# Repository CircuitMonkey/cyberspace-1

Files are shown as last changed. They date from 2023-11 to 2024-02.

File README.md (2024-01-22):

# cyberspace-1
Card Edge Slot-based 8-bit experimental computer with a Cyberpunk aesthetic.

## Why?
I wanted to make a 8-bit card-edge style computer.  8-bit computers were the first thing I learned to design in school back in the 80's.  Our mid-level education courses involved engineering students wire-wrapping and then programming their own Z80 computer system, with the next semester involving the addition and more programming of peripherals.  So I want to get back to that headspace for a bit.  I see many other hobbyists doing this with Z80, 6502 and even RP2040 chips.  This not sure yet what processor I will choose but it will be something with a good emulator environment on the Mac or Linux.

## About the name...
I want to create a system that has a Cyberpunk aesthetic and in the book Neuromancer, there is a Cyberspace "Deck" called the Cyberspace7 by Ono-Sendai and that implies the existence of Cyberspace 1 through 6.  So for my own amusement I've decided to call this experiment the Cyberspace 1 along with creating logos for Cyberspace product as well as a logo for Ono-Sendai Company.

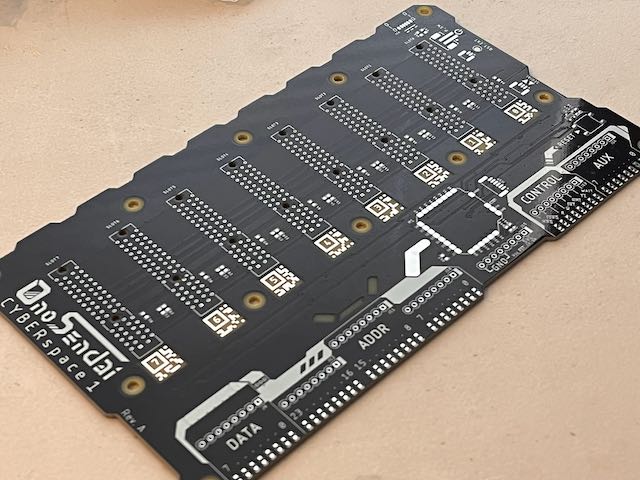
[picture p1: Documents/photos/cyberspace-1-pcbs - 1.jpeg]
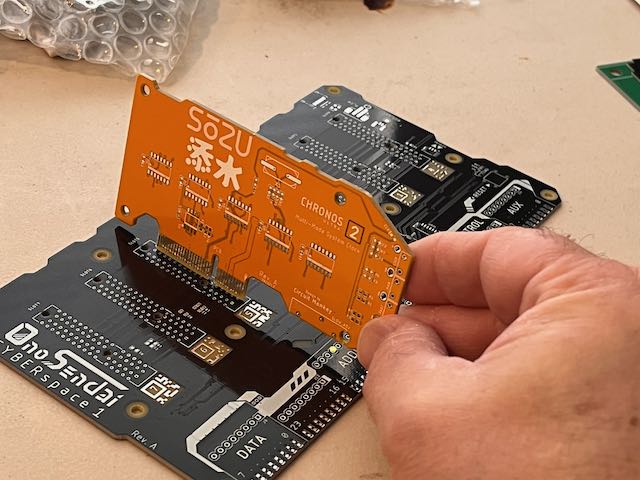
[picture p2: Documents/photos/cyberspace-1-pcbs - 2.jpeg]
&nbsp;&nbsp;&nbsp;&nbsp;

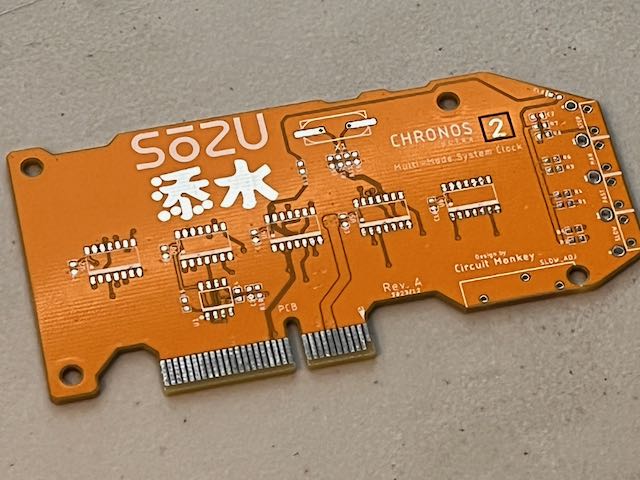
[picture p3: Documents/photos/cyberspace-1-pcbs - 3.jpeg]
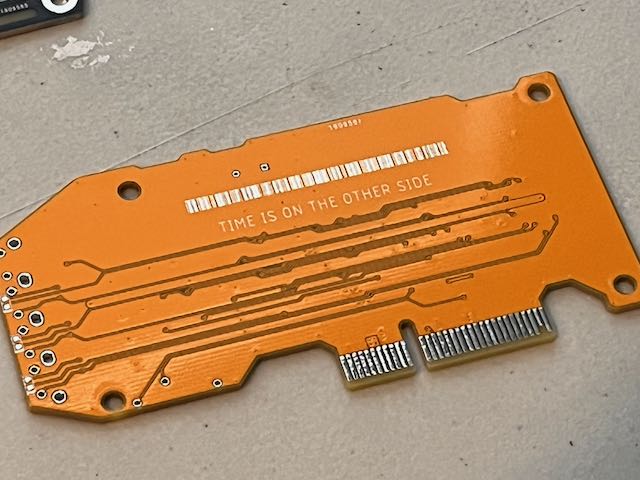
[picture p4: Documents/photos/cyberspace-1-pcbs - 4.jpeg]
&nbsp;&nbsp;&nbsp;&nbsp;

## License
I've decided to make this project with the MIT license.  Do whatever you want with it.

## Release Notes
### 2023 Early November
Created GitHub repository.

### 2023 Mid November
Roughed out basic design for all main boards.  Backplane, 6502, Memory, Clock, Video card.  Placement seems to be satisfactory.

### 2024 January
Bring up of Backplane and Clock board largely succesful!
 * Backplane. No issues found so far.
 * Clock board crystal circuit has error (used Schmidt buffer (HCT14) instead of regular buffer (HCT04). Will fix in later revision.

## To Do
Sound Card, Keyboard and game controller input card.

Each of these peripheral cards are likely to be RP2040 chips masquerading as
custom devices like the Video card will be.  I wish to use USB keyboards and
USB game (perhaps bluetooth?) controllers, so I will look at making a card with multiple USB jacks on it.  The card would handle HID and Storage devices.

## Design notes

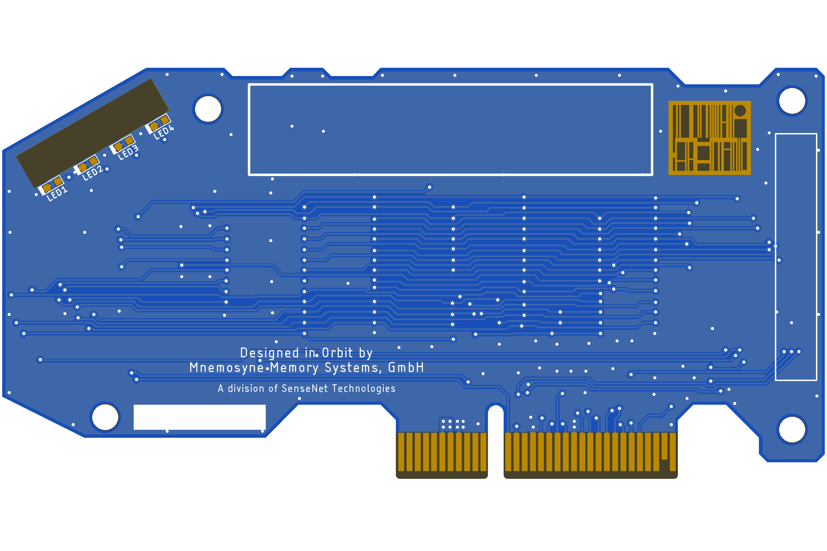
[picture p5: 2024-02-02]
Documents/photos/cyberspace-1-ram-rom-card-preview-back.png

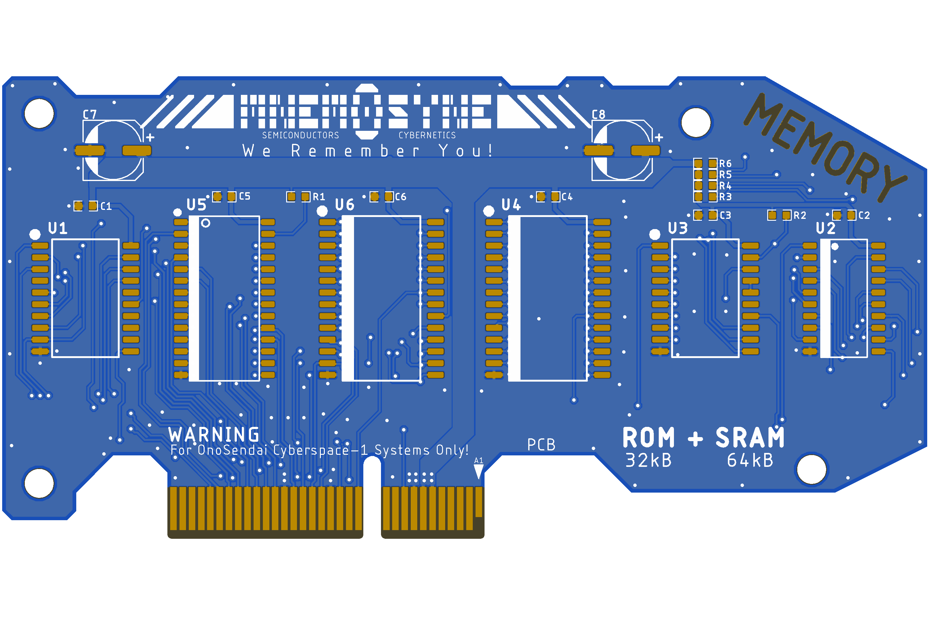
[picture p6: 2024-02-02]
Documents/photos/cyberspace-1-ram-rom-card-preview-front.png

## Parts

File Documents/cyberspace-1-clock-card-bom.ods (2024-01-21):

Cyberspace-1 Clock PCB |  |  |  |  | Rev. A |  | (2023-12)
Part | Value | Device | Package | Description | COST01 | COST10 | COST100 | MFR | MPN | LINK
PCB | PCB Fab | CYBERSPACE-1-CARD-1A | CYBERSPACE-CARD-TYPE-1A | Card for the CyberSpace 1 System | $5.00 | $2.00 | $0.70 | Circuit Monkey
R1 | 4.7K | RESISTOR0603 | 0603-RES | Resistor | $0.10 | $0.05 | $0.02
R2 | 4.7K | RESISTOR0603 | 0603-RES | Resistor | $0.10 | $0.05 | $0.02
R3 | 4.7K | RESISTOR0603 | 0603-RES | Resistor | $0.10 | $0.05 | $0.02
R4 | 1K | RESISTOR0603 | 0603-RES | Resistor | $0.10 | $0.05 | $0.02
R5 | 1K | RESISTOR0603 | 0603-RES | Resistor | $0.10 | $0.05 | $0.02
R6 | 1K | RESISTOR0603 | 0603-RES | Resistor | $0.10 | $0.05 | $0.02
R7 | 1K | RESISTOR0603 | 0603-RES | Resistor | $0.10 | $0.05 | $0.02
R8 | 1K | RESISTOR0603 | 0603-RES | Resistor | $0.10 | $0.05 | $0.02
R9 | 1K | RESISTOR0603 | 0603-RES | Resistor | $0.10 | $0.05 | $0.02
R10 | 1K | RESISTOR0603 | 0603-RES | Resistor | $0.10 | $0.05 | $0.02
R11 | 1K | RESISTOR0603 | 0603-RES | Resistor | $0.10 | $0.05 | $0.02
R12 | 1M | RESISTOR0603 | 0603-RES | Resistor | $0.10 | $0.05 | $0.02
R13 | 2K | RESISTOR0603 | 0603-RES | Resistor | $0.10 | $0.05 | $0.02
C1 | 0.1uF | CAPACITOR0603 | 0603-CAP | Capacitor | $0.12 | $0.09 | $0.05
C2 | 1uF | CAPACITOR0603 | 0603-CAP | Capacitor | $0.12 | $0.09 | $0.05
C3 | 0.1uF | CAPACITOR0603 | 0603-CAP | Capacitor | $0.12 | $0.09 | $0.05
C4 | 0.1uF | CAPACITOR0603 | 0603-CAP | Capacitor | $0.12 | $0.09 | $0.05
C5 | 22pF | CAPACITOR0603 | 0603-CAP | Capacitor | $0.12 | $0.09 | $0.05
C6 | 22pF | CAPACITOR0603 | 0603-CAP | Capacitor | $0.12 | $0.09 | $0.05
C7 | 0.1uF | CAPACITOR0603 | 0603-CAP | Capacitor | $0.12 | $0.09 | $0.05
C8 | 0.1uF | CAPACITOR0603 | 0603-CAP | Capacitor | $0.12 | $0.09 | $0.05
C9 | 0.1uF | CAPACITOR0603 | 0603-CAP | Capacitor | $0.12 | $0.09 | $0.05
C10 | 0.1uF | CAPACITOR0603 | 0603-CAP | Capacitor | $0.12 | $0.09 | $0.05
U1 | 555 | 555SOIC | SOP08 | Timer Chip | $0.70 | $0.66 | $0.40 | TI | NE555PSR
U2 | HCT08 | 74HCT08D | SOP14 | Quad AND Gate | $0.50 | $0.35 | $0.20 |  | 74HCT08D
U3 | HCT08 | 74HCT08D | SOP14 | Quad AND Gate | $0.50 | $0.35 | $0.20 |  | 74HCT08D
U4 | HCT00 | 74AHCT00D | SOP14 | Quad NAND Gate |  |  |  |  | 74HCT00D
U5 | HCT14 | 74HCT14D | SOP14 | Hex Schmidt Inverter | $0.45 | $0.35 | $0.20 |  | 74HCT14D
U6 | HCT32 | 74HCT32D | SOP14 | Quad OR | $0.45 | $0.35 | $0.20 |  | 74HCT32D
SLOW_ADJ |  | CERMET_MULTI_TURN-3006P | CERMET_MULTI_3006P_THD | Cermet Style, Multi-turn Potentiometer | $2.00 | $1.70 | $1.40 | BOURNES | 3006P | https://www.taydaelectronics.com/potentiometer-variable-resistors/cermet-potentiometers.html
CLK | RED | SMT0603 | SMD_0603 | LED SMT | $0.20 | $0.17 | $0.14
L_FAST | BLU | SMT0603 | SMD_0603 | LED SMT | $0.20 | $0.17 | $0.14
L_MAN | BLU | SMT0603 | SMD_0603 | LED SMT | $0.20 | $0.17 | $0.14
L_SLOW | BLU | SMT0603 | SMD_0603 | LED SMT | $0.20 | $0.17 | $0.14
MAN |  | TACTILESPST-RA-6X6 | TC-0202 | Push Sw. | $0.20 | $0.15 | $0.13 | CUI | TS11-674-65-*
FAST |  | TACTILESPST-RA-6X6 | TC-0202 | Push Sw. | $0.20 | $0.15 | $0.13 | CUI | TS11-674-55-*
SLOW |  | TACTILESPST-RA-6X6 | TC-0202 | Push Sw. | $0.20 | $0.15 | $0.13 | CUI | TS11-674-55-*
STEP |  | TACTILESPST-RA-6X6 | TC-0202 | Push Sw. | $0.20 | $0.15 | $0.13 | CUI | TS11-674-55-*
X1 | 1-14MHz | 2PATS_DUAL_SMD_THD | ATSXXXX | Crystal

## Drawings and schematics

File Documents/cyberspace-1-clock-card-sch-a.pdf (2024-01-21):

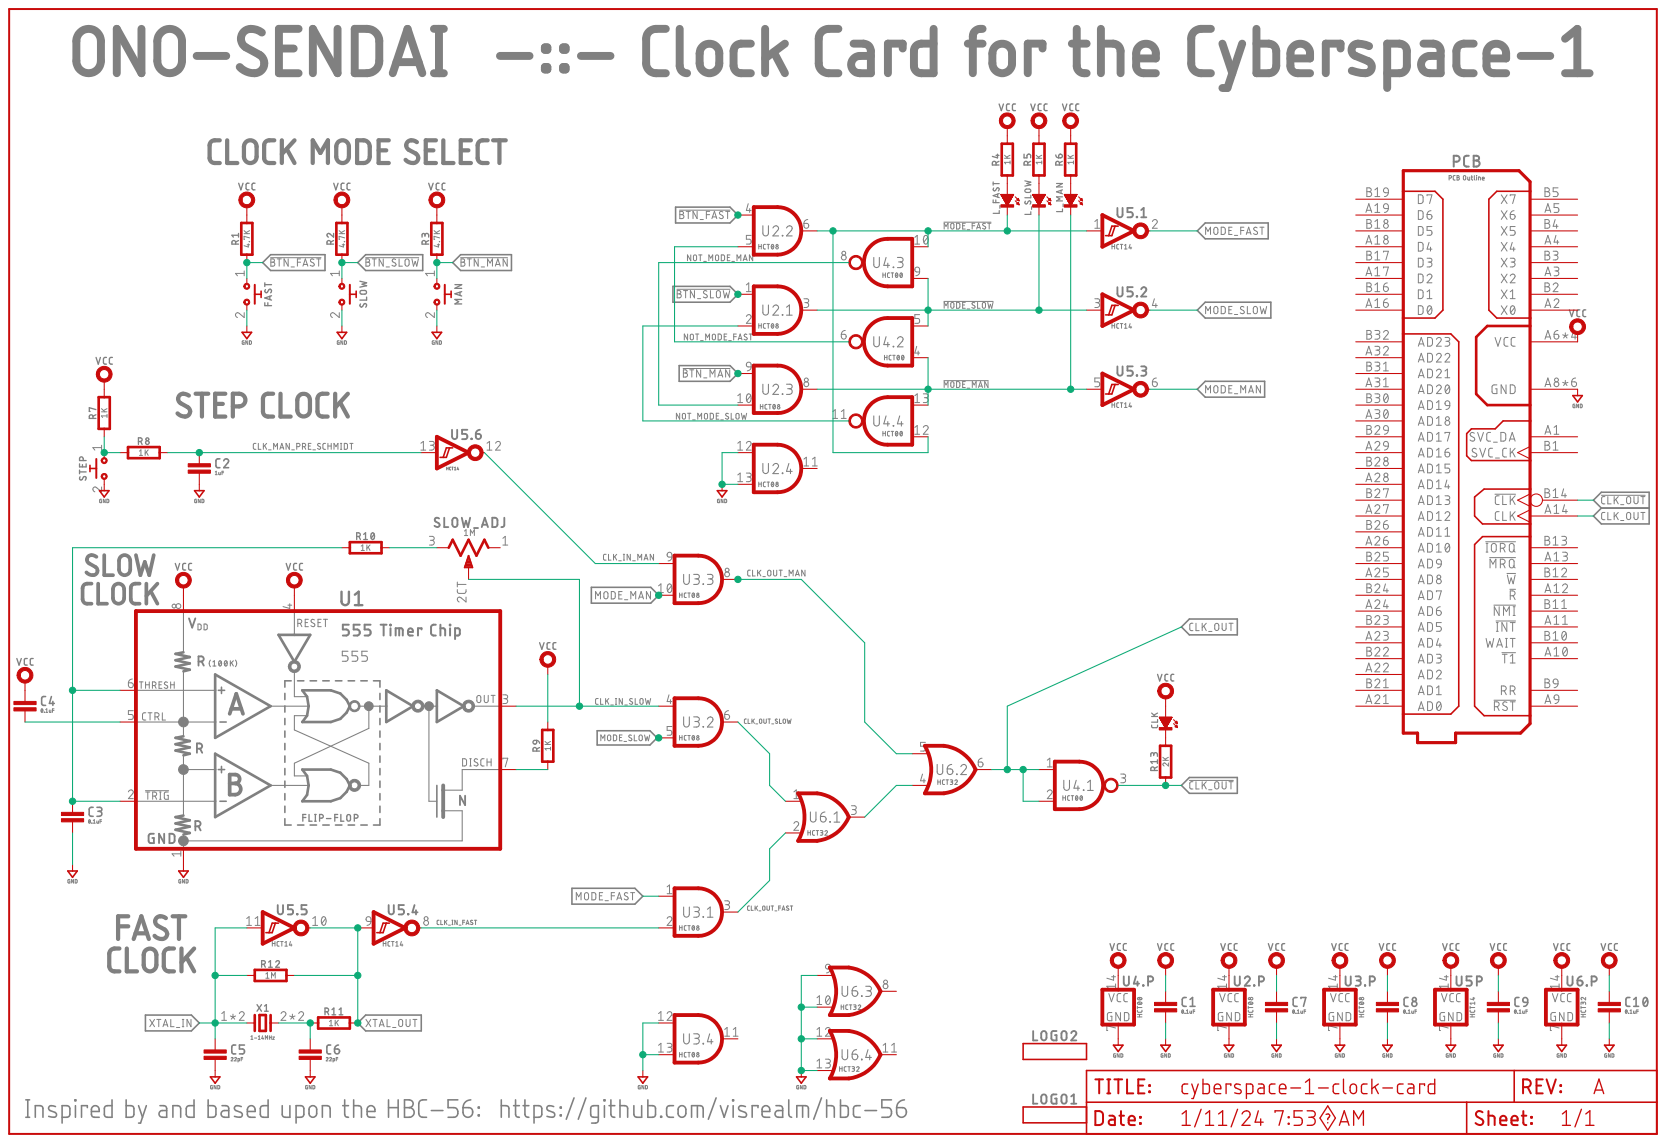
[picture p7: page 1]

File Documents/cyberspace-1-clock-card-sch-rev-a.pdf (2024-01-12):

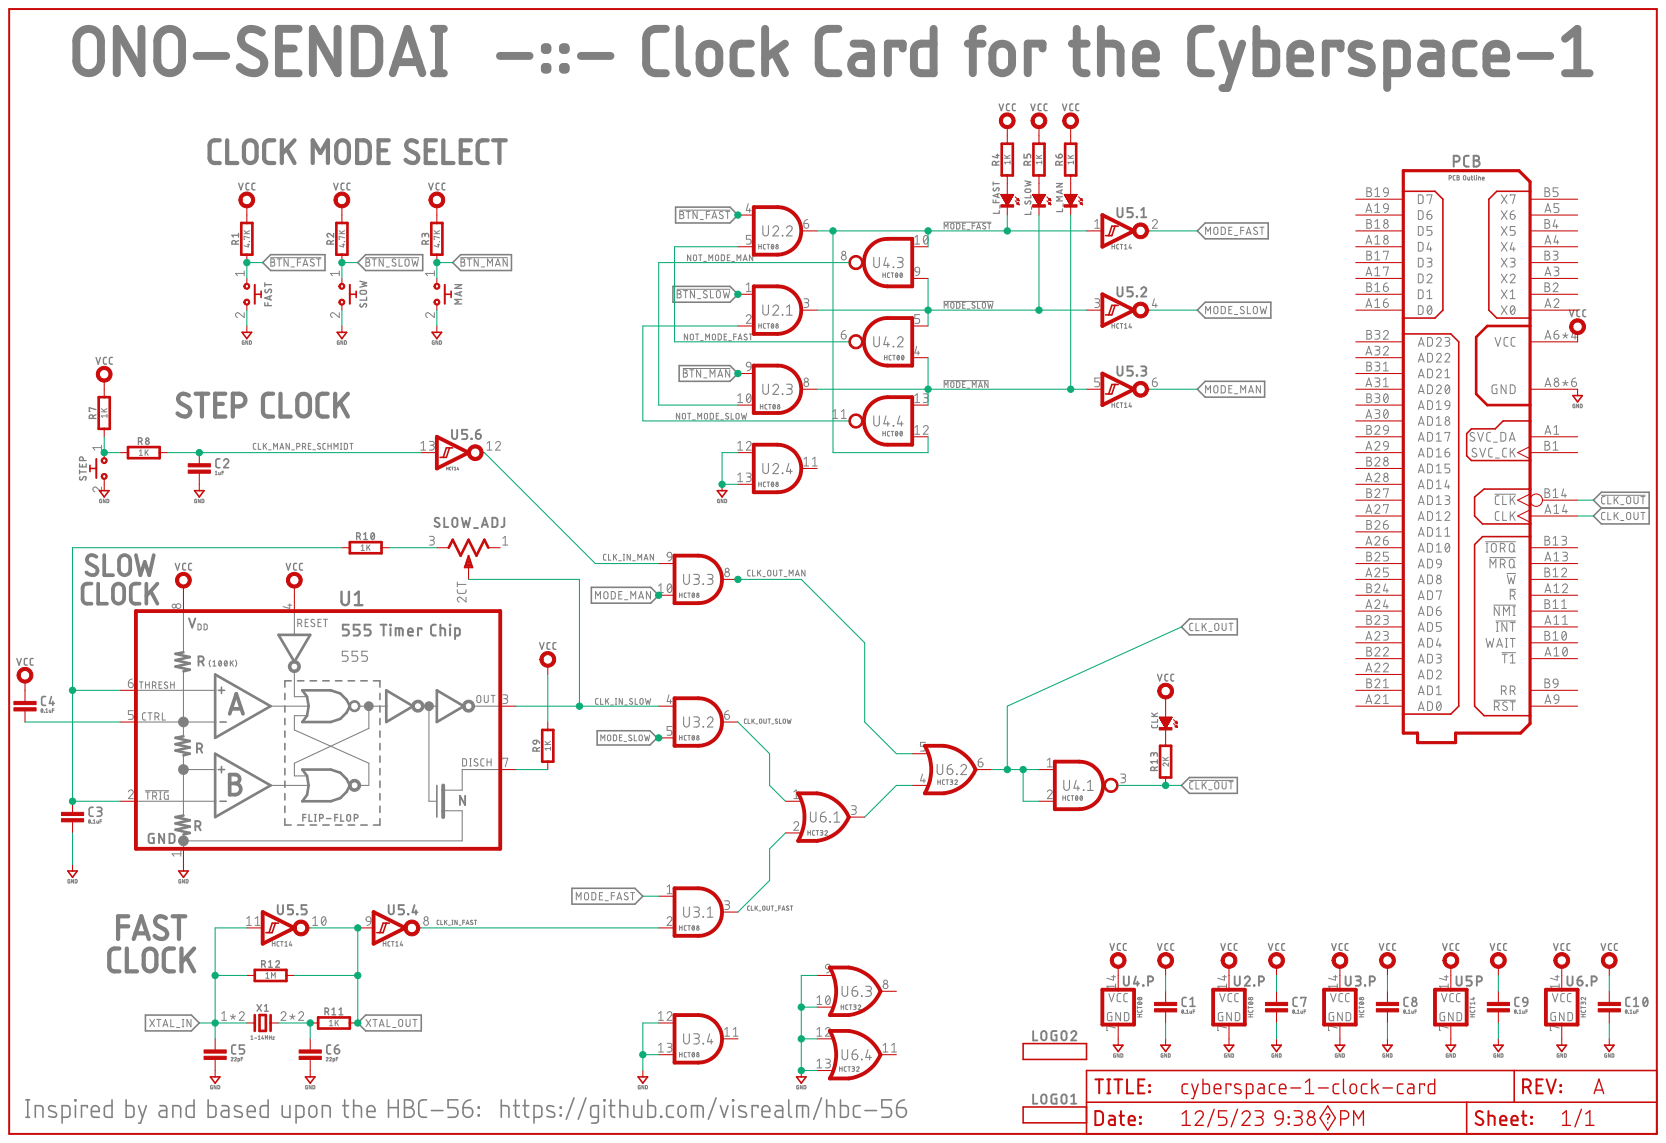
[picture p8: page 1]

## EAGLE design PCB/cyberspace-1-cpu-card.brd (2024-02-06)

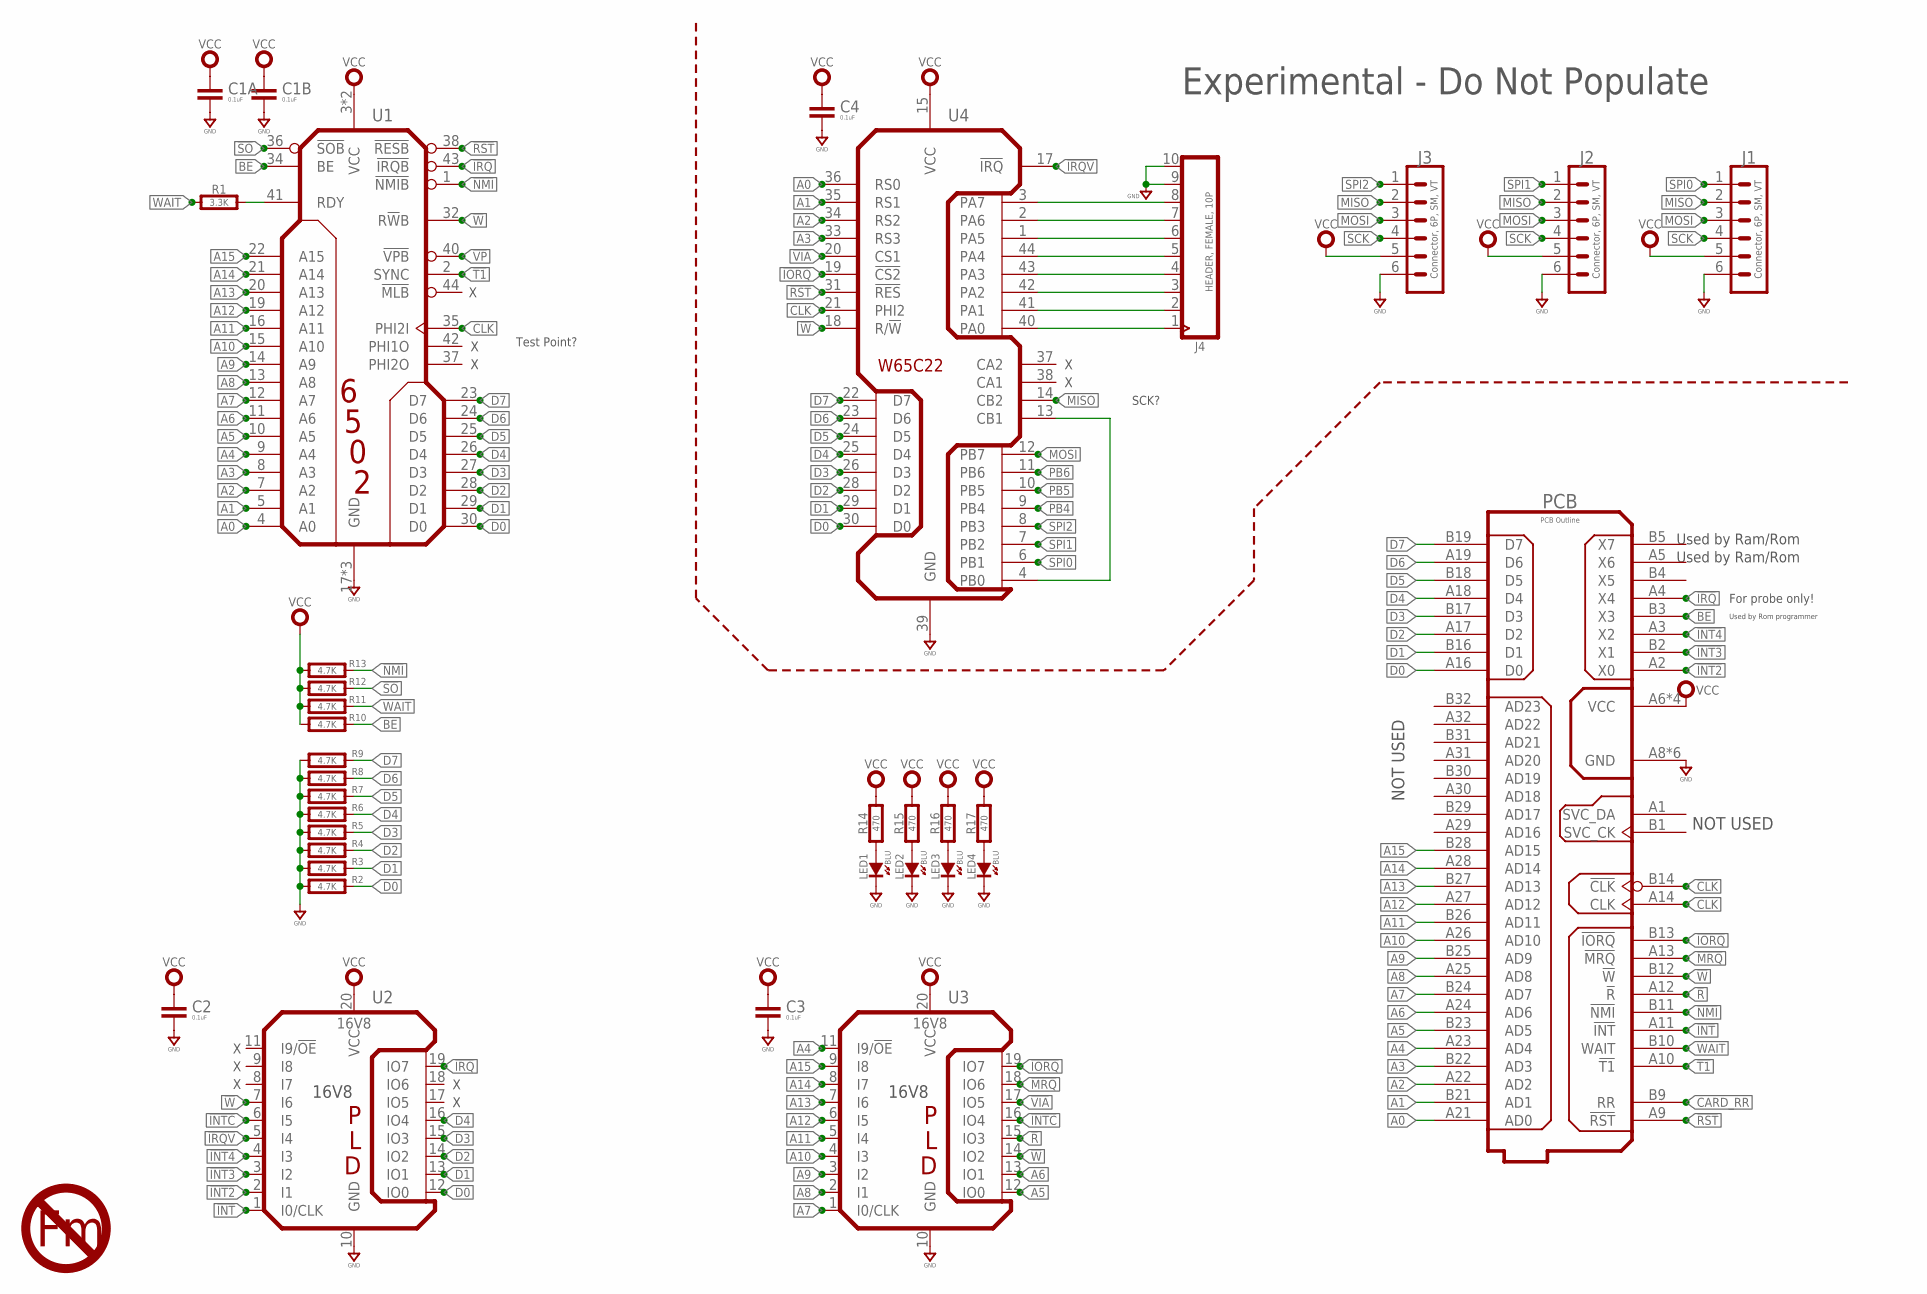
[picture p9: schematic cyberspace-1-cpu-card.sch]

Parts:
C1A, C1B, C2, C3, C4: 0.1uF; 0603-CAP
J1, J2, J3: Connector, 6P, SM, VT; BM06B-SRSS-TB
J4: HEADER, FEMALE, 10P; H10-2.54
LED1, LED2, LED3, LED4: BLU; SMD_0603
PCB: PCB Outline; CYBERSPACE-CARD-TYPE-1A
R1: 3.3K; 0603-RES
R2, R3, R4, R5, R6, R7, R8, R9, R10, R11, R12, R13: 4.7K; 0603-RES
R14, R15, R16, R17: 470; 0603-RES
U1: 6502 Processor; TQFP-44-10
U2, U3: 16V8; SOP20
U4: W65C22; TQFP-44-10
U$2: NO-FERMIUM-5MM

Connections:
!CLK: PCB.B14 (!CLK)
!INT: PCB.A11 (!INT), U2.1 (I0/CLK)
!INT2: PCB.A2 (X0), U2.2 (I1)
!INT3: PCB.B2 (X1), U2.3 (I2)
!INT4: PCB.A3 (X2), U2.4 (I3)
!INTC: U2.6 (I5), U3.16 (IO4)
!IORQ: PCB.B13 (!IORQ), U3.19 (IO7), U4.19 (!CS2)
!IRQ: PCB.A4 (X4), U1.43 (!IRQB), U2.19 (IO7)
!IRQV: U2.5 (I4), U4.17 (!IRQ)
!MRQ: PCB.A13 (!MRQ), U3.18 (IO6)
!NMI: PCB.B11 (!NMI), R13.2, U1.1 (!NMIB)
!R: PCB.A12 (!R), U3.15 (IO3)
!RST: PCB.A9 (!RST), U1.38 (!RESB), U4.31 (!RES)
!SO: R12.2, U1.36 (!SOB)
!T1: PCB.A10 (!T1), U1.2 (SYNC)
!VIA: U3.17 (IO5), U4.20 (CS1)
!VP: U1.40 (!VPB)
!W: PCB.B12 (!W), U1.32 (R!W!B), U2.7 (I6), U3.14 (IO2), U4.18 (R/!W)
A0: PCB.A21 (AD0), U1.4 (A0), U4.36 (RS0)
A1: PCB.B21 (AD1), U1.5 (A1), U4.35 (RS1)
A2: PCB.A22 (AD2), U1.7 (A2), U4.34 (RS2)
A3: PCB.B22 (AD3), U1.8 (A3), U4.33 (RS3)
A4: PCB.A23 (AD4), U1.9 (A4), U3.11 (I9/!OE)
A5: PCB.B23 (AD5), U1.10 (A5), U3.12 (IO0)
A6: PCB.A24 (AD6), U1.11 (A6), U3.13 (IO1)
A7: PCB.B24 (AD7), U1.12 (A7), U3.1 (I0/CLK)
A8: PCB.A25 (AD8), U1.13 (A8), U3.2 (I1)
A9: PCB.B25 (AD9), U1.14 (A9), U3.3 (I2)
A10: PCB.A26 (AD10), U1.15 (A10), U3.4 (I3)
A11: PCB.B26 (AD11), U1.16 (A11), U3.5 (I4)
A12: PCB.A27 (AD12), U1.19 (A12), U3.6 (I5)
A13: PCB.B27 (AD13), U1.20 (A13), U3.7 (I6)
A14: PCB.A28 (AD14), U1.21 (A14), U3.8 (I7)
A15: PCB.B28 (AD15), U1.22 (A15), U3.9 (I8)
BE: PCB.B3 (X3), R10.2, U1.34 (BE)
CARD_RR: PCB.B9 (RR)
CLK: PCB.A14 (CLK), U1.35 (PHI2I), U4.21 (PHI2)
D0: PCB.A16 (D0), R2.2, U1.30 (D0), U2.12 (IO0), U4.30 (D0)
D1: PCB.B16 (D1), R3.2, U1.29 (D1), U2.13 (IO1), U4.29 (D1)
D2: PCB.A17 (D2), R4.2, U1.28 (D2), U2.14 (IO2), U4.28 (D2)
D3: PCB.B17 (D3), R5.2, U1.27 (D3), U2.15 (IO3), U4.26 (D3)
D4: PCB.A18 (D4), R6.2, U1.26 (D4), U2.16 (IO4), U4.25 (D4)
D5: PCB.B18 (D5), R7.2, U1.25 (D5), U4.24 (D5)
D6: PCB.A19 (D6), R8.2, U1.24 (D6), U4.23 (D6)
D7: PCB.B19 (D7), R9.2, U1.23 (D7), U4.22 (D7)
GND: C1A.2, C1B.2, C2.2, C3.2, C4.2, J1.6, J2.6, J3.6, J4.9, J4.10, LED1.K (C), LED2.K (C), LED3.K (C), LED4.K (C), PCB.A8 (GND), PCB.A15 (GND), PCB.A20 (GND), PCB.B8 (GND), PCB.B15 (GND), PCB.B20 (GND), R2.1, R3.1, R4.1, R5.1, R6.1, R7.1, R8.1, R9.1, U1.17 (GND), U1.18 (GND), U1.39 (GND), U2.10 (GND), U3.10 (GND), U4.39 (GND)
MISO: J1.2, J2.2, J3.2, U4.14 (CB2)
MOSI: J1.3, J2.3, J3.3, U4.12 (PB7)
unnamed: J4.1, U4.40 (PA0)
unnamed: J4.2, U4.41 (PA1)
unnamed: J4.3, U4.42 (PA2)
unnamed: J4.4, U4.43 (PA3)
unnamed: J4.5, U4.44 (PA4)
unnamed: J4.6, U4.1 (PA5)
unnamed: J4.7, U4.2 (PA6)
unnamed: J4.8, U4.3 (PA7)
unnamed: U4.4 (PB0), U4.13 (CB1)
unnamed: R1.2, U1.41 (RDY)
unnamed: LED1.A, R14.1
unnamed: LED2.A, R15.1
unnamed: LED3.A, R16.1
unnamed: LED4.A, R17.1
PB4: U4.9 (PB4)
PB5: U4.10 (PB5)
PB6: U4.11 (PB6)
SCK: J1.4, J2.4, J3.4
SPI0: J1.1, U4.6 (PB1)
SPI1: J2.1, U4.7 (PB2)
SPI2: J3.1, U4.8 (PB3)
VCC: C1A.1, C1B.1, C2.1, C3.1, C4.1, J1.5, J2.5, J3.5, PCB.A6 (VCC), PCB.A7 (VCC), PCB.B6 (VCC), PCB.B7 (VCC), R10.1, R11.1, R12.1, R13.1, R14.2, R15.2, R16.2, R17.2, U1.3 (VCC), U1.31 (VCC), U2.20 (VCC), U3.20 (VCC), U4.15 (VCC)
WAIT: PCB.B10 (WAIT), R1.1, R11.2

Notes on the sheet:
Experimental - Do Not Populate
NOT USED
Used by Ram/Rom
X X X
X X
SCK?
Test Point?
For probe only!
Used by Rom programmer

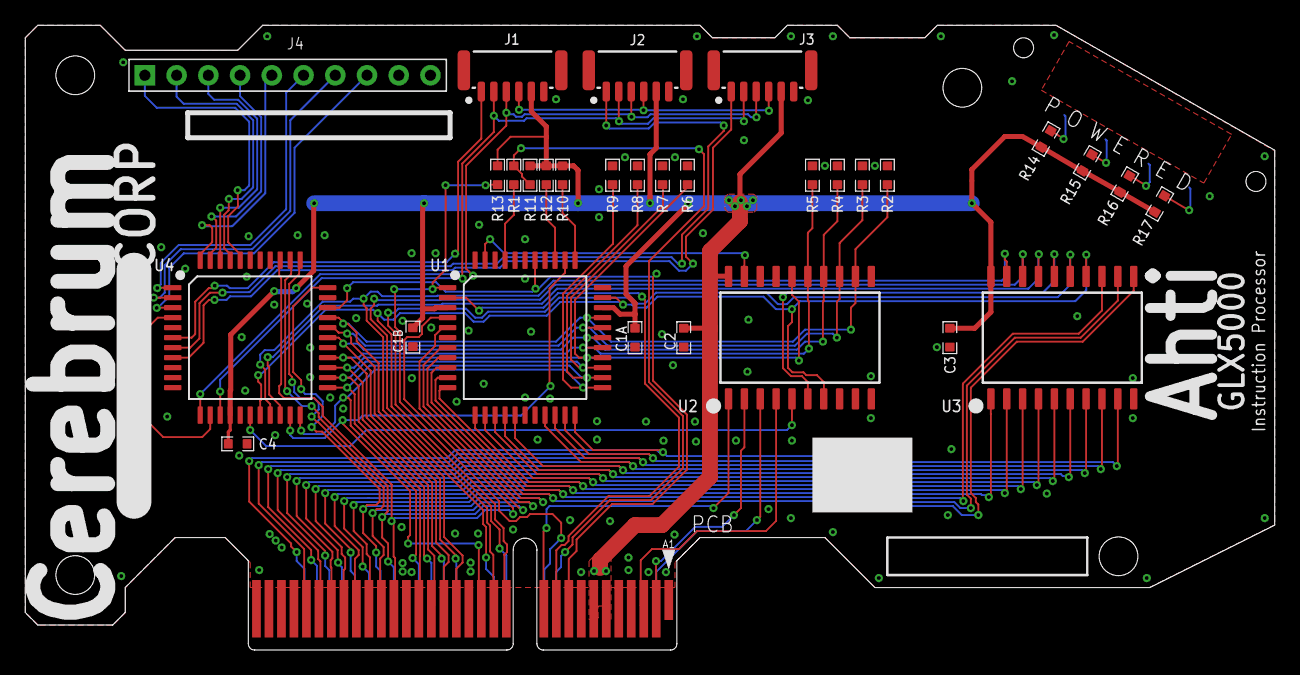
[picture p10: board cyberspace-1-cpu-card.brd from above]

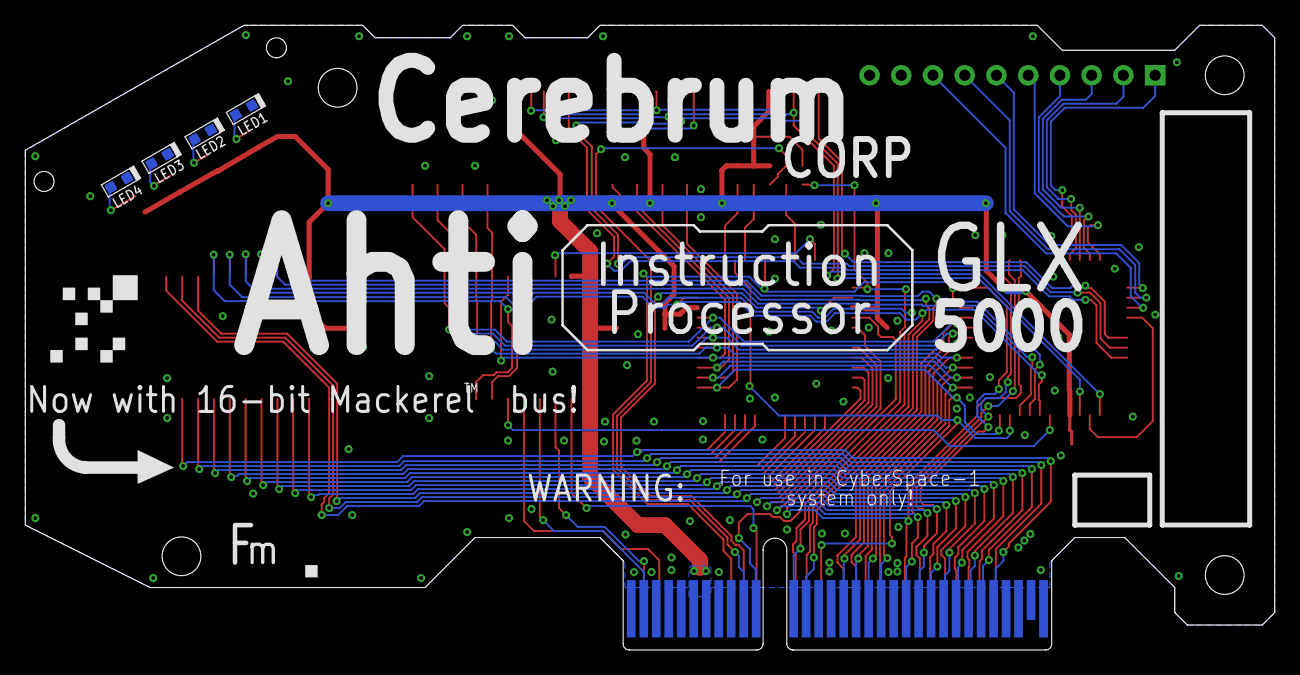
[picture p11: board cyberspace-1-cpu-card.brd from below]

Board: 2 copper layers, 100.0 x 50.0 mm, 36 parts (5 on the bottom side), 65 nets.

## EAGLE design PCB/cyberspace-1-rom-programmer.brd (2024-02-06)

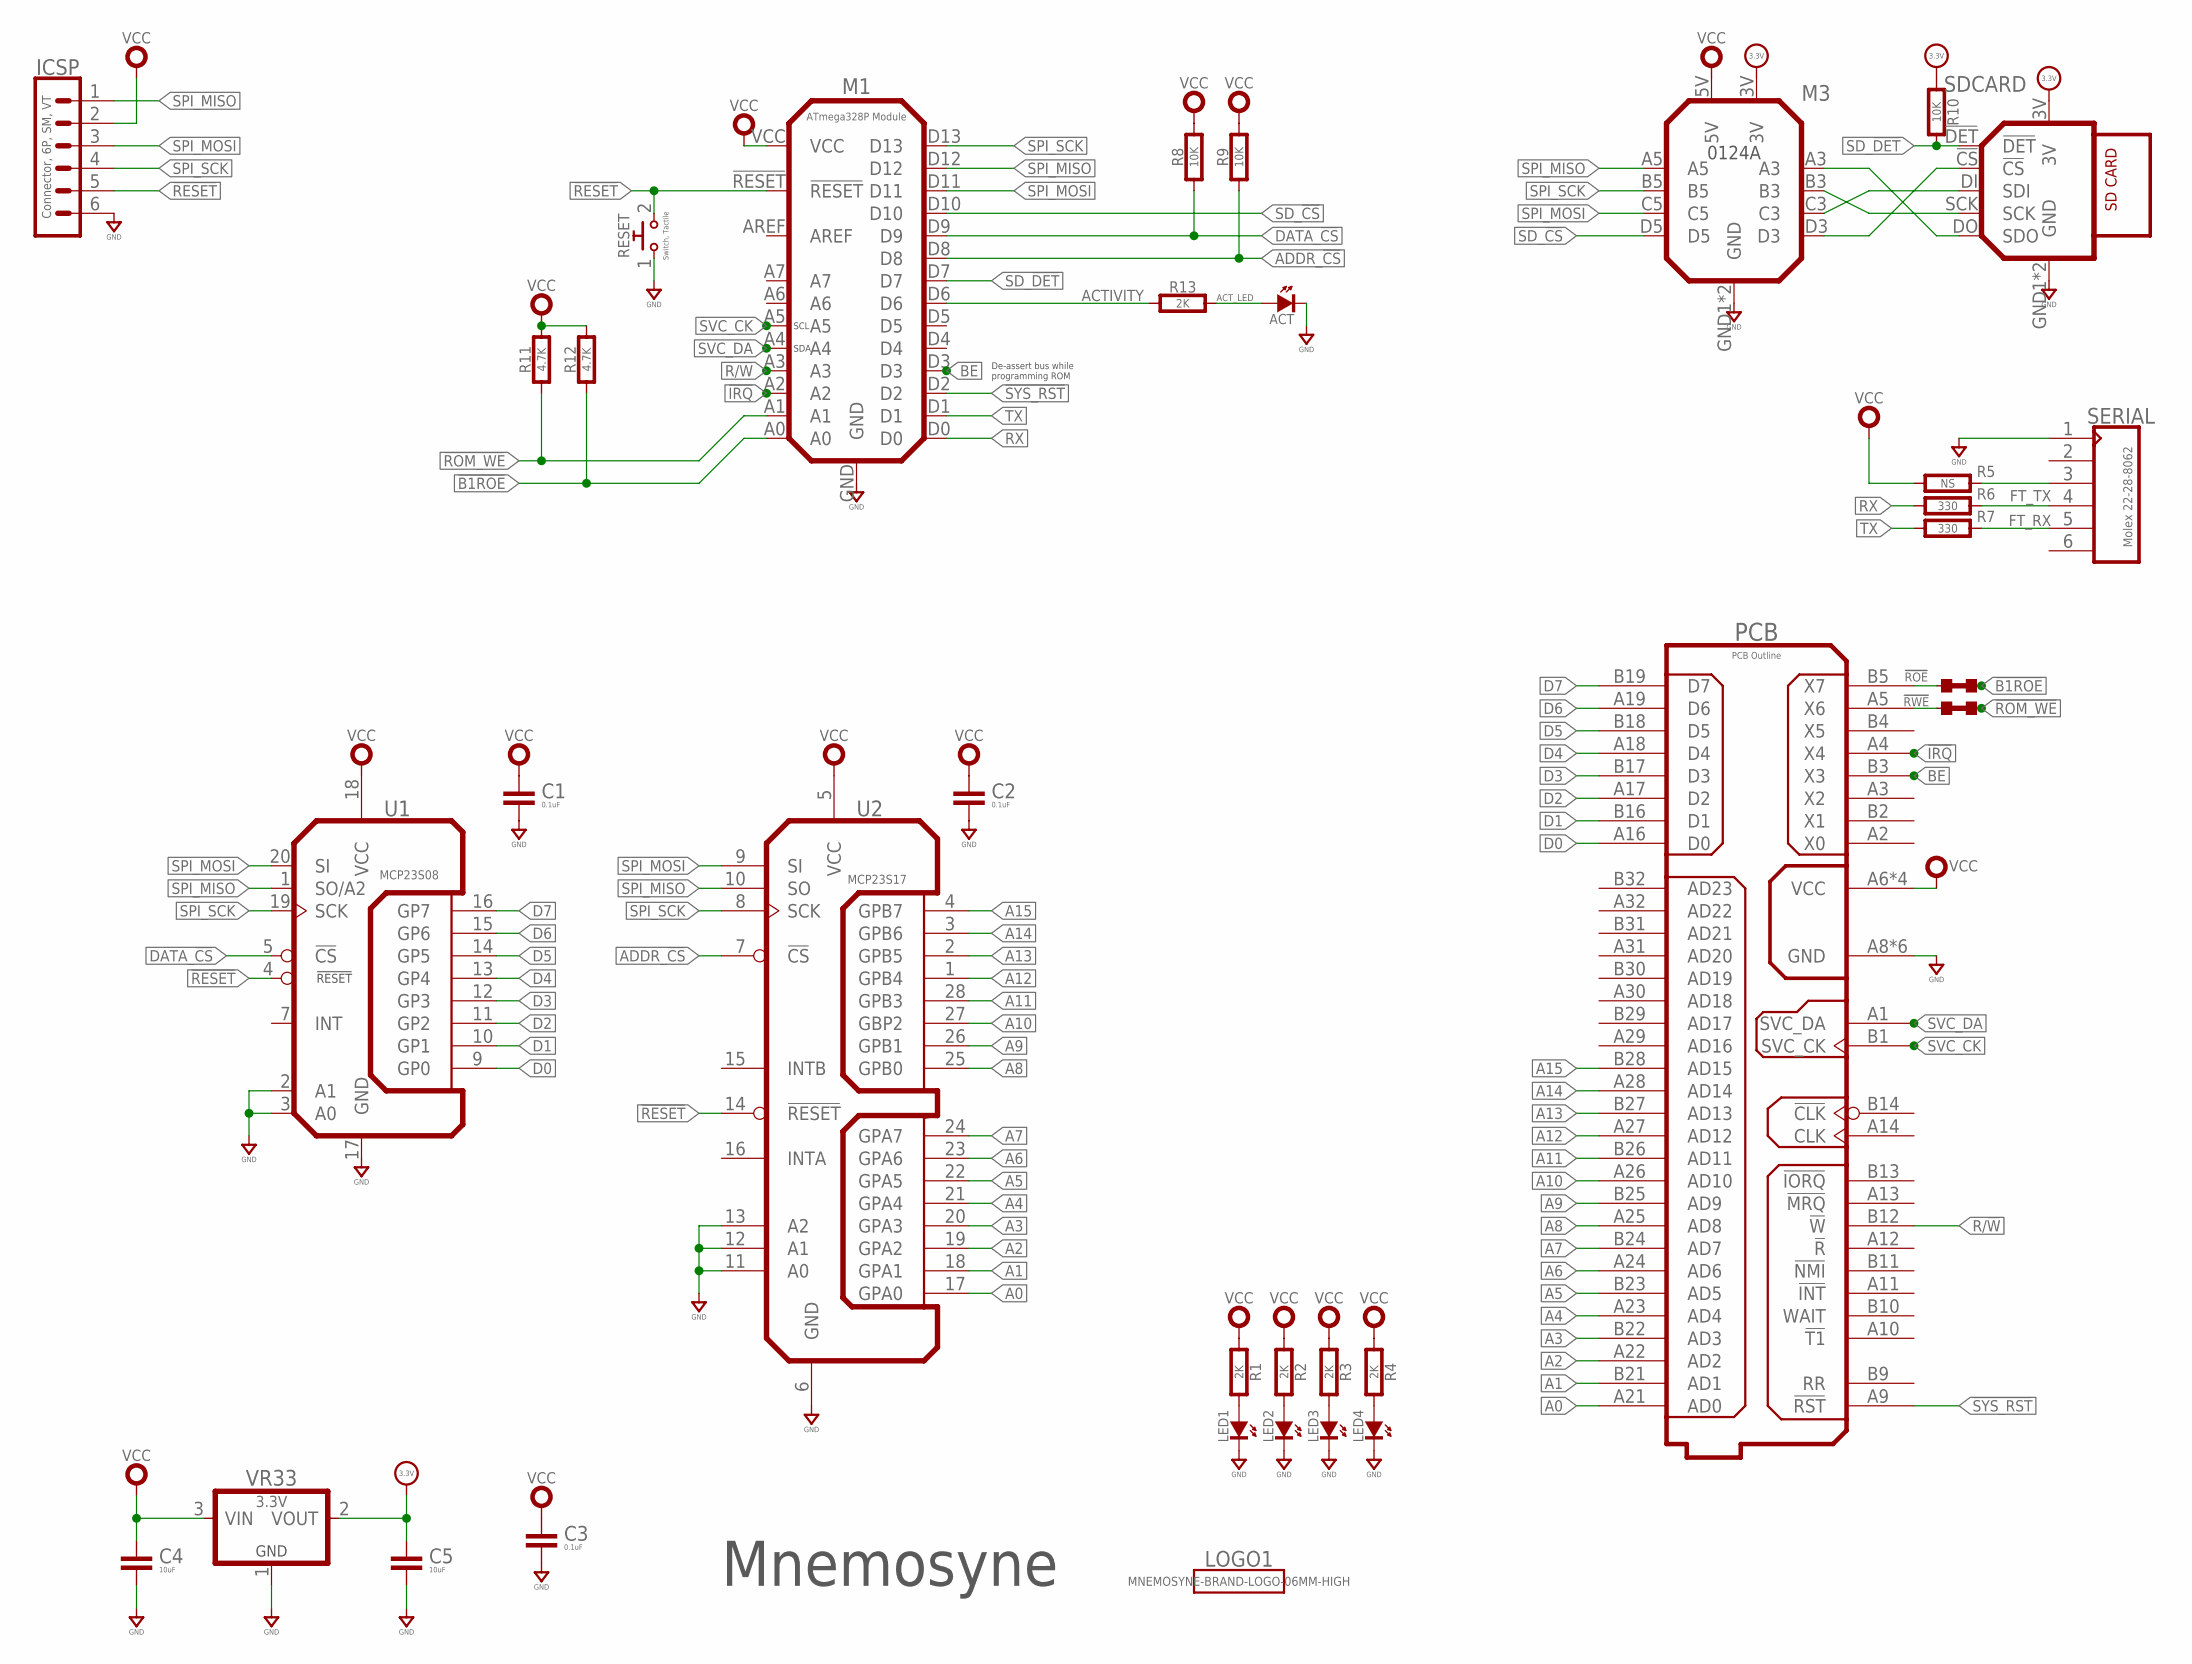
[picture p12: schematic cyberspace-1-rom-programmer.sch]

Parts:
!ROE: NP; 0603-SHORT
!RWE: NP; 0603-SHORT
ACT: SMT0603; SMD_0603
C1, C2, C3: 0.1uF; 0603-CAP
C4, C5: 10uF; 0603-CAP
ICSP: Connector, 6P, SM, VT; BM06B-SRSS-TB
LED1, LED2, LED3, LED4: SMT0603; SMD_0603
LOGO1: MNEMOSYNE-BRAND-LOGO-06MM-HIGH; MNEMOSYNE-06MM
M1: ATmega328P Module; 0119A
M3: 0124A
PCB: PCB Outline; CYBERSPACE-CARD-TYPE-1A
R1, R2, R3, R4, R13: 2K; 0603-RES
R5: NS; 0603-RES
R6, R7: 330; 0603-RES
R8, R9, R10: 10K; 0603-RES
R11, R12: 4.7K; 0603-RES
RESET: Switch, Tactile; TC-0202
SDCARD: 0127REV-A; 0127A
SERIAL: Molex 22-28-8062; MA06X1-RA-THD
U1: MCP23S08; QFN-20
U2: MCP23S17; QFN-28-6X6
VR33: 3.3V; SOT-23

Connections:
!B1ROE: !ROE.4 (2), M1.A0, R12.1
!IRQ: M1.A2, PCB.A4 (X4)
!RESET: ICSP.5, M1.!RESET, RESET.2, U1.4 (!RESET), U2.14 (!RESET)
!ROM_WE: !RWE.4 (2), M1.A1, R11.1
!SYS_RST: M1.D2, PCB.A9 (!RST)
+3.3V: C5.1, M3.3V, R10.2, SDCARD.3V, VR33.2 (VOUT)
A0: PCB.A21 (AD0), U2.17 (GPA0)
A1: PCB.B21 (AD1), U2.18 (GPA1)
A2: PCB.A22 (AD2), U2.19 (GPA2)
A3: PCB.B22 (AD3), U2.20 (GPA3)
A4: PCB.A23 (AD4), U2.21 (GPA4)
A5: PCB.B23 (AD5), U2.22 (GPA5)
A6: PCB.A24 (AD6), U2.23 (GPA6)
A7: PCB.B24 (AD7), U2.24 (GPA7)
A8: PCB.A25 (AD8), U2.25 (GPB0)
A9: PCB.B25 (AD9), U2.26 (GPB1)
A10: PCB.A26 (AD10), U2.27 (GBP2)
A11: PCB.B26 (AD11), U2.28 (GPB3)
A12: PCB.A27 (AD12), U2.1 (GPB4)
A13: PCB.B27 (AD13), U2.2 (GPB5)
A14: PCB.A28 (AD14), U2.3 (GPB6)
A15: PCB.B28 (AD15), U2.4 (GPB7)
ACTIVITY: M1.D6, R13.1
ACT_LED: ACT.A, R13.2
ADDR_!CS: M1.D8, R9.1, U2.7 (!CS)
BE: M1.D3, PCB.B3 (X3)
D0: PCB.A16 (D0), U1.9 (GP0)
D1: PCB.B16 (D1), U1.10 (GP1)
D2: PCB.A17 (D2), U1.11 (GP2)
D3: PCB.B17 (D3), U1.12 (GP3)
D4: PCB.A18 (D4), U1.13 (GP4)
D5: PCB.B18 (D5), U1.14 (GP5)
D6: PCB.A19 (D6), U1.15 (GP6)
D7: PCB.B19 (D7), U1.16 (GP7)
DATA_!CS: M1.D9, R8.1, U1.5 (!CS)
FT_RX: R7.1, SERIAL.5
FT_TX: R6.1, SERIAL.4
GND: ACT.K (C), C1.2, C2.2, C3.2, C4.2, C5.2, ICSP.6, LED1.K (C), LED2.K (C), LED3.K (C), LED4.K (C), M1.GND, M3.GND1 (GND), M3.GND2 (GND), PCB.A8 (GND), PCB.A15 (GND), PCB.A20 (GND), PCB.B8 (GND), PCB.B15 (GND), PCB.B20 (GND), RESET.1, SDCARD.GND1 (GND), SDCARD.GND2 (GND), SERIAL.1, U1.2 (A1), U1.3 (A0), U1.17 (GND), U2.6 (GND), U2.11 (A0), U2.12 (A1), U2.13 (A2), VR33.1 (GND)
unnamed: M3.A3, SDCARD.DO (SDO)
unnamed: M3.B3, SDCARD.SCK
unnamed: M3.C3, SDCARD.DI (SDI)
unnamed: R5.1, SERIAL.3
unnamed: M3.D3, SDCARD.!CS
unnamed: LED1.A, R1.2
unnamed: LED2.A, R2.2
unnamed: LED3.A, R3.2
unnamed: !ROE.3 (1), PCB.B5 (X7)
unnamed: !RWE.3 (1), PCB.A5 (X6)
unnamed: LED4.A, R4.2
R/!W: M1.A3, PCB.B12 (!W)
RX: M1.D0, R6.2
SD_!CS: M1.D10, M3.D5
SD_!DET: M1.D7, R10.1, SDCARD.!DET
SPI_MISO: ICSP.1, M1.D12, M3.A5, U1.1 (SO/A2), U2.10 (SO)
SPI_MOSI: ICSP.3, M1.D11, M3.C5, U1.20 (SI), U2.9 (SI)
SPI_SCK: ICSP.4, M1.D13, M3.B5, U1.19 (SCK), U2.8 (SCK)
SVC_CK: M1.A5, PCB.B1 (SVC_CK)
SVC_DA: M1.A4, PCB.A1 (SVC_DA)
TX: M1.D1, R7.2
VCC: C1.1, C2.1, C3.1, C4.1, ICSP.2, M1.VCC, M3.5V, PCB.A6 (VCC), PCB.A7 (VCC), PCB.B6 (VCC), PCB.B7 (VCC), R1.1, R2.1, R3.1, R4.1, R5.2, R8.2, R9.2, R11.2, R12.2, U1.18 (VCC), U2.5 (VCC), VR33.3 (VIN)

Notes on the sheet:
SDA
SCL
Mnemosyne
De-assert bus while programming ROM

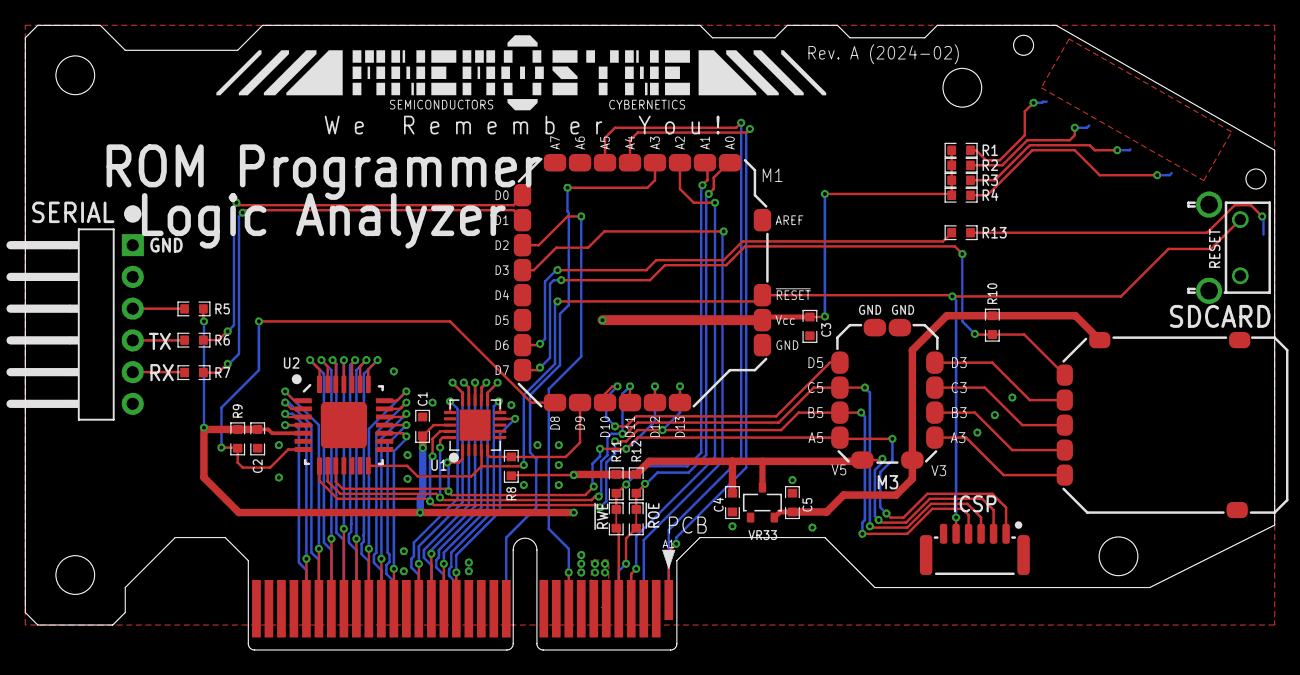
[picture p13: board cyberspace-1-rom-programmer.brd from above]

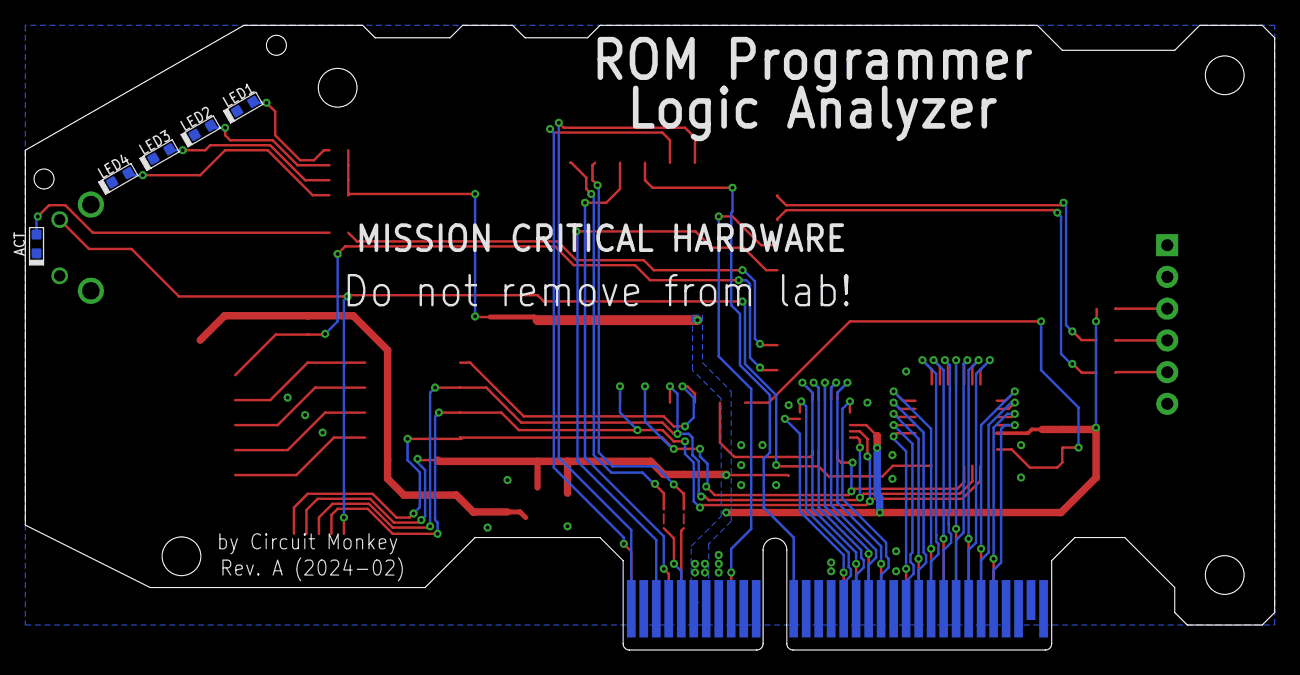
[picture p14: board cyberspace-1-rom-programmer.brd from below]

Board: 2 copper layers, 100.0 x 50.0 mm, 36 parts (5 on the bottom side), 60 nets.

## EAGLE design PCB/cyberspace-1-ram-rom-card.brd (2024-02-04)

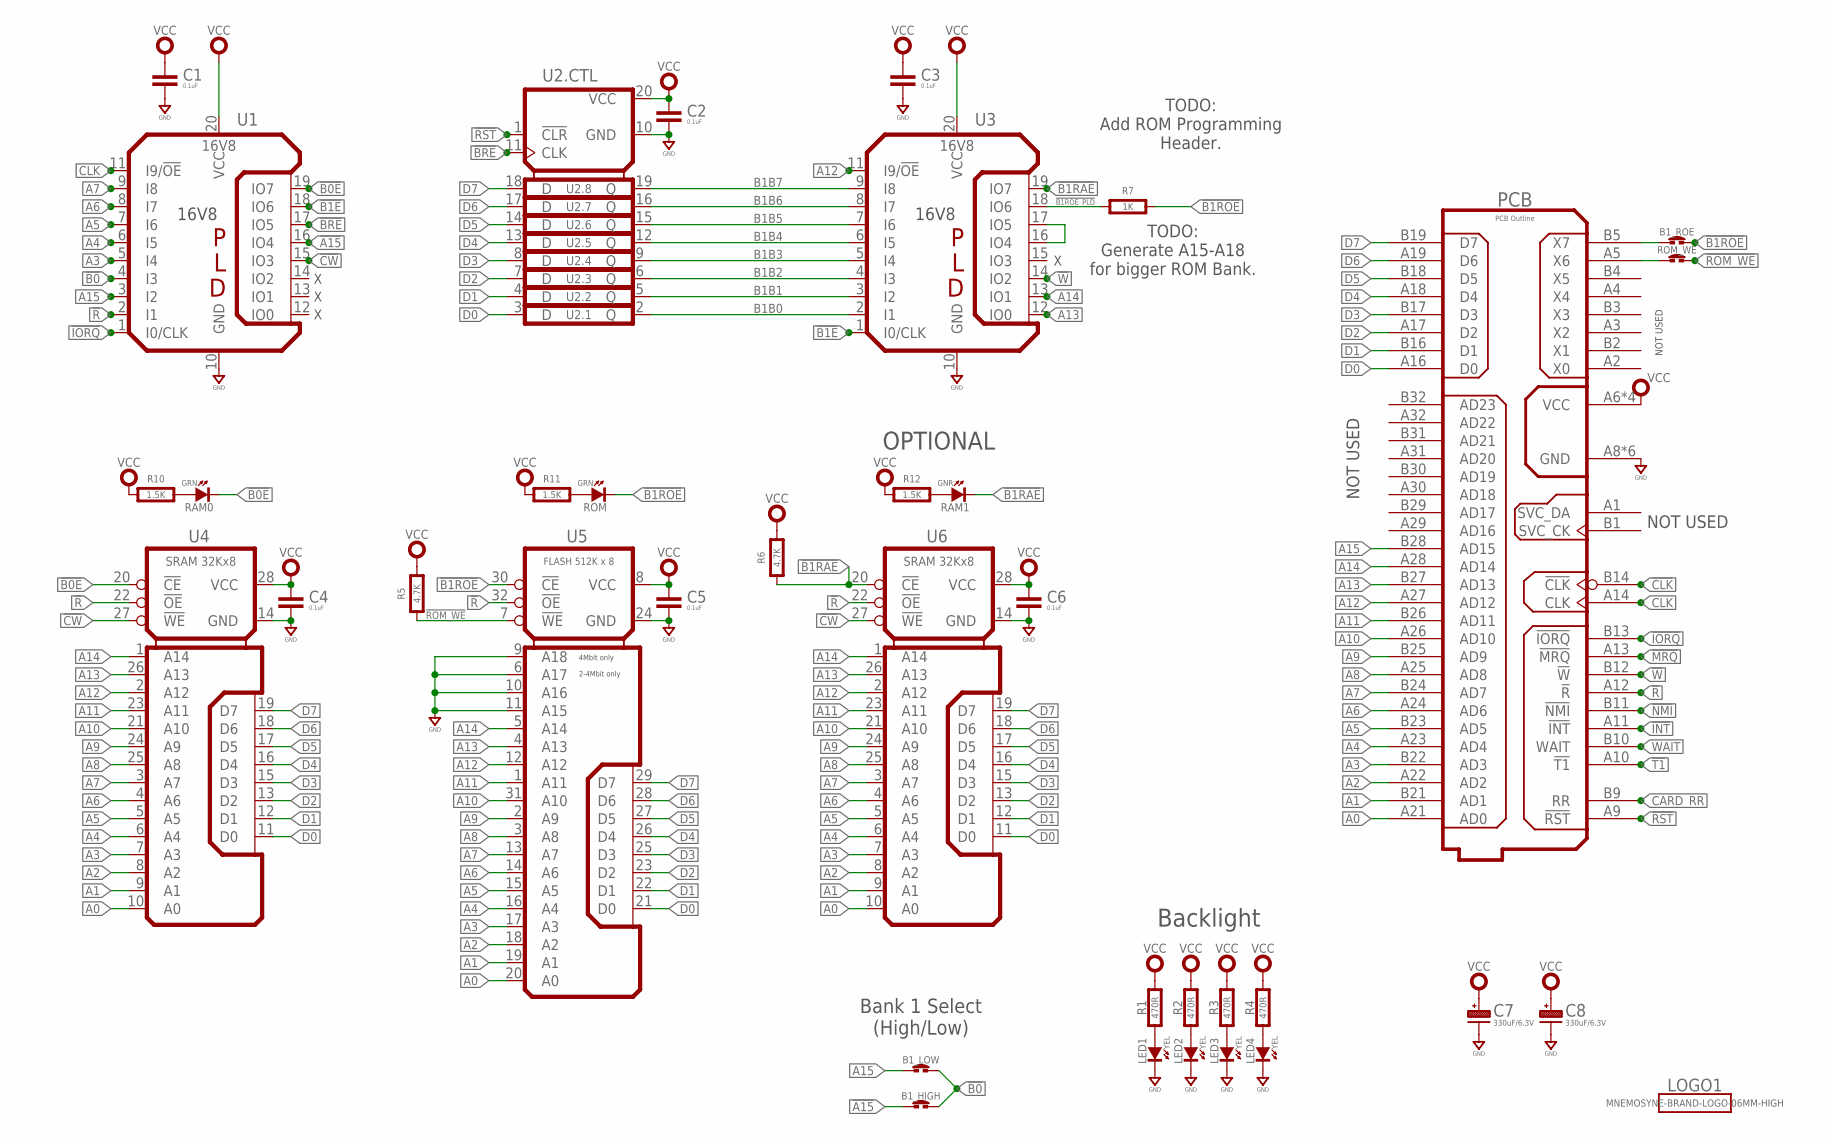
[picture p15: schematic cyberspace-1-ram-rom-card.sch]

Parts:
B1_HIGH, B1_LOW, B1_ROE: SOLDER_JUMPER-60MIL-RND; SOLDER_JUMP_60MIL_RND
C1, C2, C3, C4, C5, C6: 0.1uF; 0603-CAP
C7, C8: 330uF/6.3V; CAP_ALUM_SMT_6.3
LED1, LED2, LED3, LED4: YEL; SMD_0603
LOGO1: MNEMOSYNE-BRAND-LOGO-06MM-HIGH; MNEMOSYNE-06MM
PCB: PCB Outline; CYBERSPACE-CARD-TYPE-1A
R1, R2, R3, R4: 470R; 0603-RES
R5, R6: 4.7K; 0603-RES
R7: 1K; 0603-RES
R10, R11, R12: 1.5K; 0603-RES
RAM0: GRN; SMD_0603
RAM1: GNR; SMD_0603
ROM: GRN; SMD_0603
ROM_WE: SOLDER_JUMPER-60MIL-RND; SOLDER_JUMP_60MIL_RND
U1, U3: 16V8; SOP20
U2: 74AHCT273NS; SO20
U4, U6: SRAM 32Kx8; SOP28-330W
U5: FLASH 512K x 8; TSOP32-14X8MM

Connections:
!A15: B1_HIGH.1, U1.16 (IO4)
!B0: B1_HIGH.2, B1_LOW.2, U1.4 (I3)
!B0E: RAM0.K (C), U1.19 (IO7), U4.20 (!CE)
!B1E: U1.18 (IO6), U3.1 (I0/CLK)
!B1RAE: R6.1, RAM1.K (C), U3.19 (IO7), U6.20 (!CE)
!B1ROE: B1_ROE.2, R7.2, ROM.K (C), U5.30 (!CE)
!B1ROE_PLD: R7.1, U3.18 (IO6)
!BRE: U1.17 (IO5), U2.11 (CLK)
!CLK: PCB.B14 (!CLK)
!CW: U1.15 (IO3), U4.27 (!WE), U6.27 (!WE)
!INT: PCB.A11 (!INT)
!IORQ: PCB.B13 (!IORQ), U1.1 (I0/CLK)
!MRQ: PCB.A13 (!MRQ)
!NMI: PCB.B11 (!NMI)
!R: PCB.A12 (!R), U1.2 (I1), U4.22 (!OE), U5.32 (!OE), U6.22 (!OE)
!ROM_WE: R5.1, ROM_WE.2, U5.7 (!WE)
!RST: PCB.A9 (!RST), U2.1 (!CLR)
!T1: PCB.A10 (!T1)
!W: PCB.B12 (!W), U3.14 (IO2)
A0: PCB.A21 (AD0), U4.10 (A0), U5.20 (A0), U6.10 (A0)
A1: PCB.B21 (AD1), U4.9 (A1), U5.19 (A1), U6.9 (A1)
A2: PCB.A22 (AD2), U4.8 (A2), U5.18 (A2), U6.8 (A2)
A3: PCB.B22 (AD3), U1.5 (I4), U4.7 (A3), U5.17 (A3), U6.7 (A3)
A4: PCB.A23 (AD4), U1.6 (I5), U4.6 (A4), U5.16 (A4), U6.6 (A4)
A5: PCB.B23 (AD5), U1.7 (I6), U4.5 (A5), U5.15 (A5), U6.5 (A5)
A6: PCB.A24 (AD6), U1.8 (I7), U4.4 (A6), U5.14 (A6), U6.4 (A6)
A7: PCB.B24 (AD7), U1.9 (I8), U4.3 (A7), U5.13 (A7), U6.3 (A7)
A8: PCB.A25 (AD8), U4.25 (A8), U5.3 (A8), U6.25 (A8)
A9: PCB.B25 (AD9), U4.24 (A9), U5.2 (A9), U6.24 (A9)
A10: PCB.A26 (AD10), U4.21 (A10), U5.31 (A10), U6.21 (A10)
A11: PCB.B26 (AD11), U4.23 (A11), U5.1 (A11), U6.23 (A11)
A12: PCB.A27 (AD12), U3.11 (I9/!OE), U4.2 (A12), U5.12 (A12), U6.2 (A12)
A13: PCB.B27 (AD13), U3.12 (IO0), U4.26 (A13), U5.4 (A13), U6.26 (A13)
A14: PCB.A28 (AD14), U3.13 (IO1), U4.1 (A14), U5.5 (A14), U6.1 (A14)
A15: B1_LOW.1, PCB.B28 (AD15), U1.3 (I2)
B1B0: U2.2 (Q), U3.2 (I1)
B1B1: U2.5 (Q), U3.3 (I2)
B1B2: U2.6 (Q), U3.4 (I3)
B1B3: U2.9 (Q), U3.5 (I4)
B1B4: U2.12 (Q), U3.6 (I5)
B1B5: U2.15 (Q), U3.7 (I6)
B1B6: U2.16 (Q), U3.8 (I7)
B1B7: U2.19 (Q), U3.9 (I8)
CARD_RR: PCB.B9 (RR)
CLK: PCB.A14 (CLK), U1.11 (I9/!OE)
D0: PCB.A16 (D0), U2.3 (D), U4.11 (D0), U5.21 (D0), U6.11 (D0)
D1: PCB.B16 (D1), U2.4 (D), U4.12 (D1), U5.22 (D1), U6.12 (D1)
D2: PCB.A17 (D2), U2.7 (D), U4.13 (D2), U5.23 (D2), U6.13 (D2)
D3: PCB.B17 (D3), U2.8 (D), U4.15 (D3), U5.25 (D3), U6.15 (D3)
D4: PCB.A18 (D4), U2.13 (D), U4.16 (D4), U5.26 (D4), U6.16 (D4)
D5: PCB.B18 (D5), U2.14 (D), U4.17 (D5), U5.27 (D5), U6.17 (D5)
D6: PCB.A19 (D6), U2.17 (D), U4.18 (D6), U5.28 (D6), U6.18 (D6)
D7: PCB.B19 (D7), U2.18 (D), U4.19 (D7), U5.29 (D7), U6.19 (D7)
GND: C1.2, C2.2, C3.2, C4.2, C5.2, C6.2, C7.- (N), C8.- (N), LED1.K (C), LED2.K (C), LED3.K (C), LED4.K (C), PCB.A8 (GND), PCB.A15 (GND), PCB.A20 (GND), PCB.B8 (GND), PCB.B15 (GND), PCB.B20 (GND), U1.10 (GND), U2.10 (GND), U3.10 (GND), U4.14 (GND), U5.6 (A17), U5.9 (A18), U5.10 (A16), U5.11 (A15), U5.24 (GND), U6.14 (GND)
unnamed: U3.16 (IO4), U3.17 (IO5)
unnamed: LED1.A, R1.1
unnamed: LED2.A, R2.1
unnamed: R10.2, RAM0.A
unnamed: LED3.A, R3.1
unnamed: LED4.A, R4.1
unnamed: R11.2, ROM.A
unnamed: R12.2, RAM1.A
unnamed: B1_ROE.1, PCB.B5 (X7)
unnamed: PCB.A5 (X6), ROM_WE.1
VCC: C1.1, C2.1, C3.1, C4.1, C5.1, C6.1, C7.+, C8.+, PCB.A6 (VCC), PCB.A7 (VCC), PCB.B6 (VCC), PCB.B7 (VCC), R1.2, R2.2, R3.2, R4.2, R5.2, R6.2, R10.1, R11.1, R12.1, U1.20 (VCC), U2.20 (VCC), U3.20 (VCC), U4.28 (VCC), U5.8 (VCC), U6.28 (VCC)
WAIT: PCB.B10 (WAIT)

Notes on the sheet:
NOT USED
X X X
OPTIONAL
TODO: Generate A15-A18 for bigger ROM Bank.
TODO: Add ROM Programming Header.
Backlight
Bank 1 Select (High/Low)

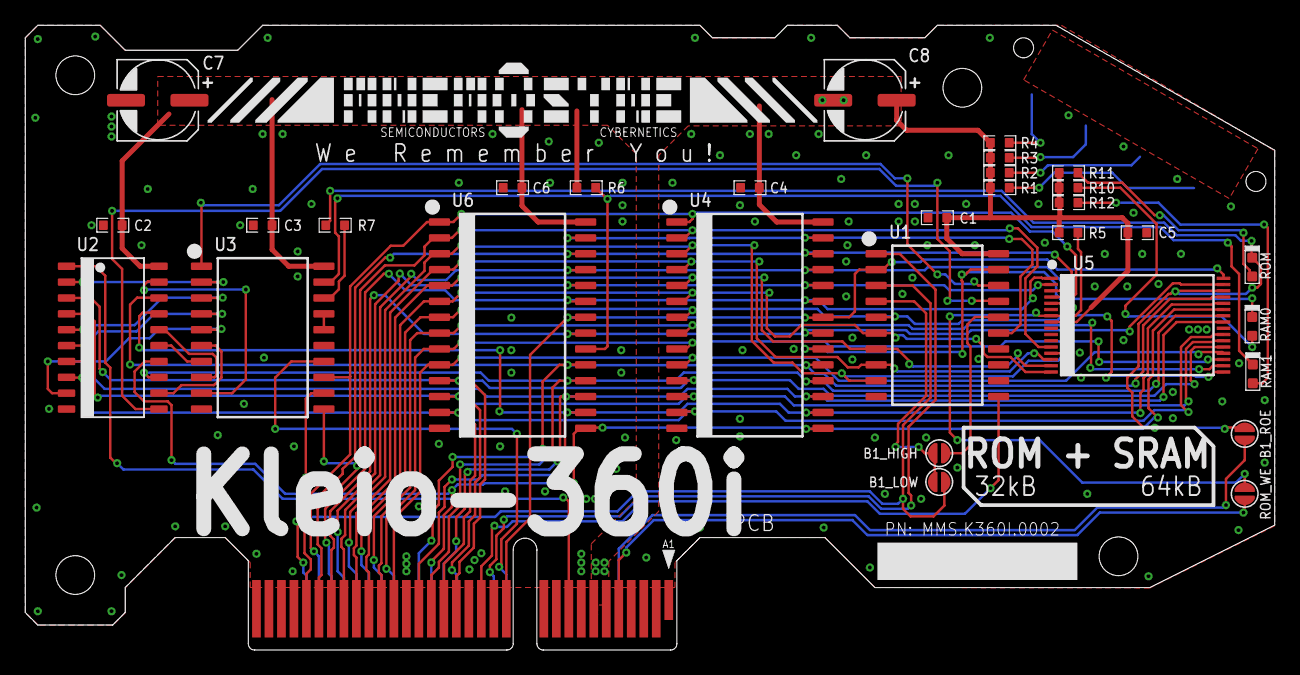
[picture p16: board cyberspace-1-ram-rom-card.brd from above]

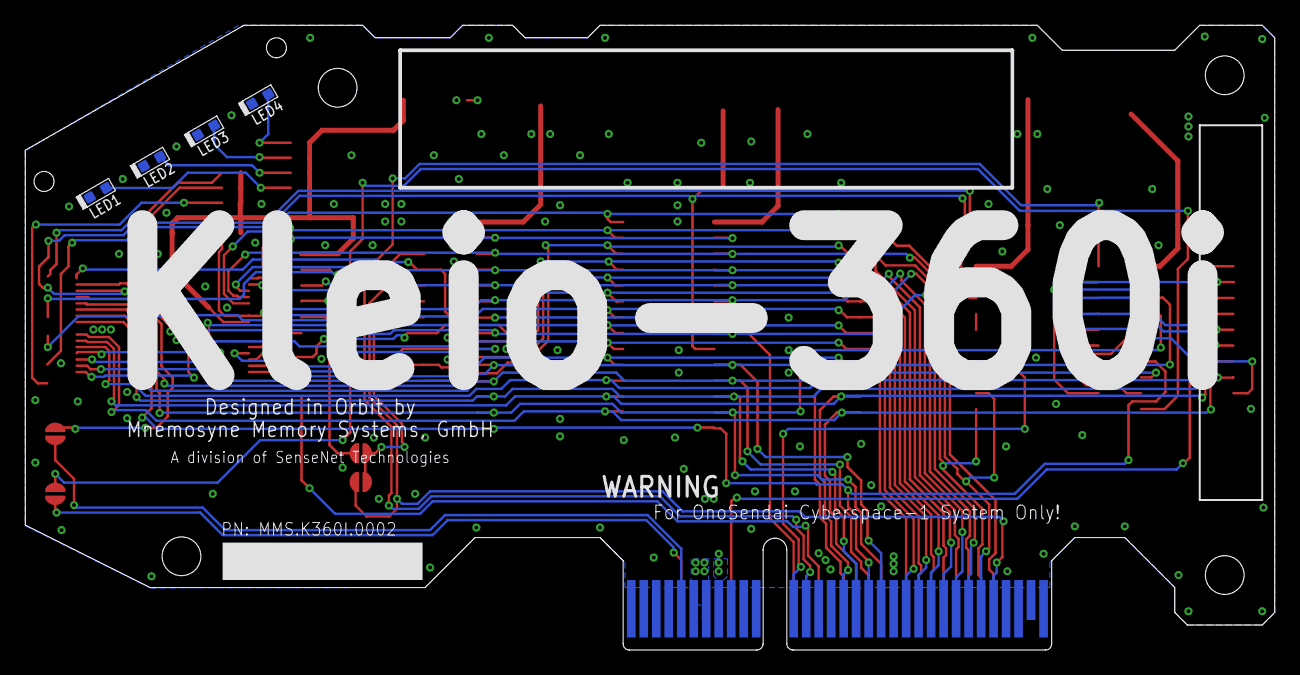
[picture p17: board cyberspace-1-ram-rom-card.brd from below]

Board: 2 copper layers, 100.0 x 50.0 mm, 37 parts (4 on the bottom side), 59 nets.

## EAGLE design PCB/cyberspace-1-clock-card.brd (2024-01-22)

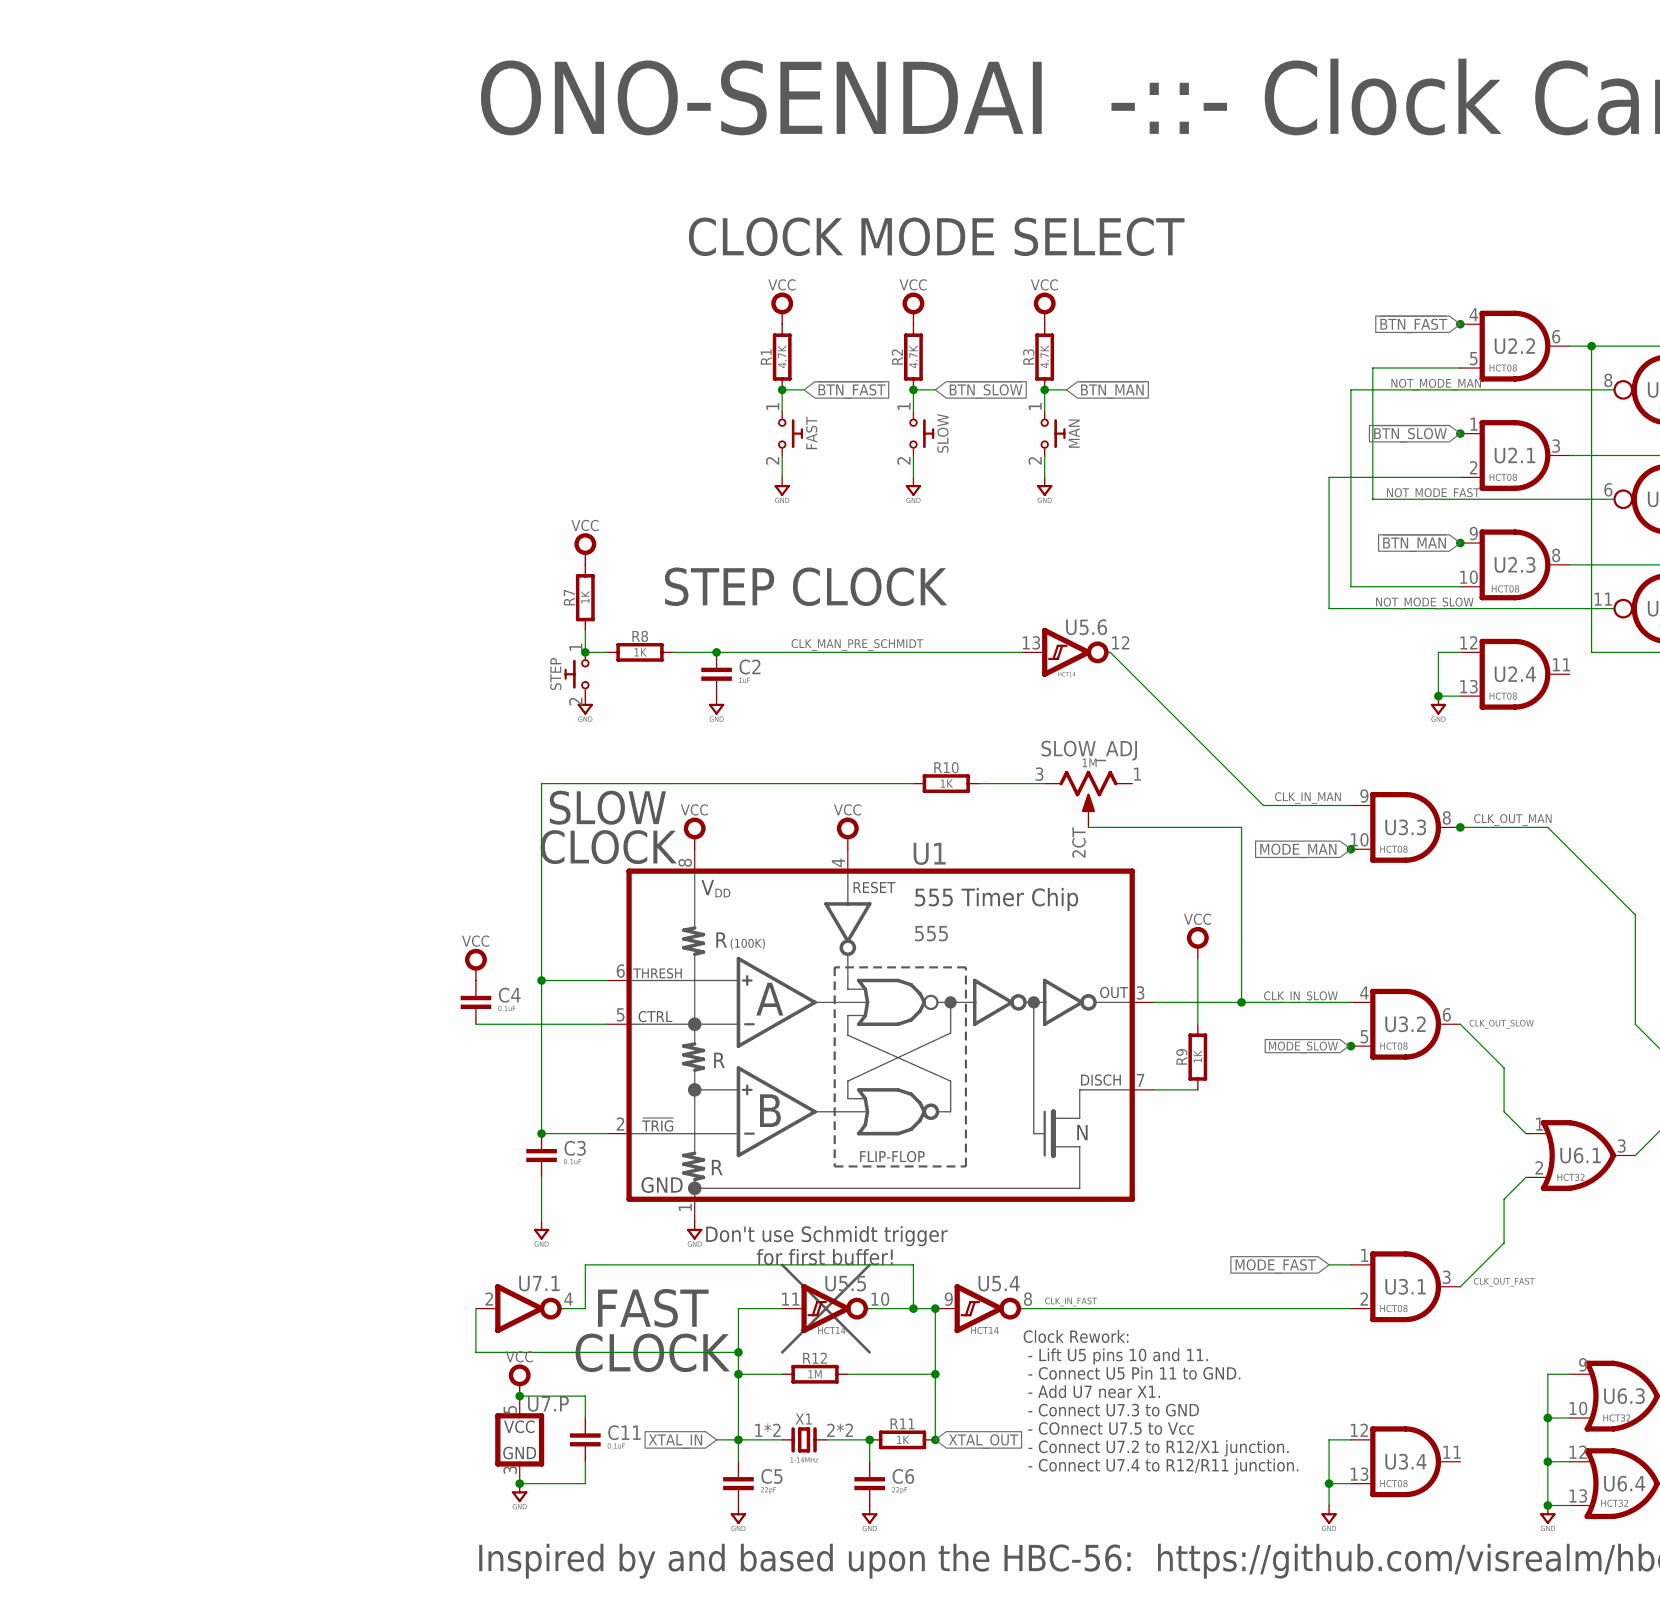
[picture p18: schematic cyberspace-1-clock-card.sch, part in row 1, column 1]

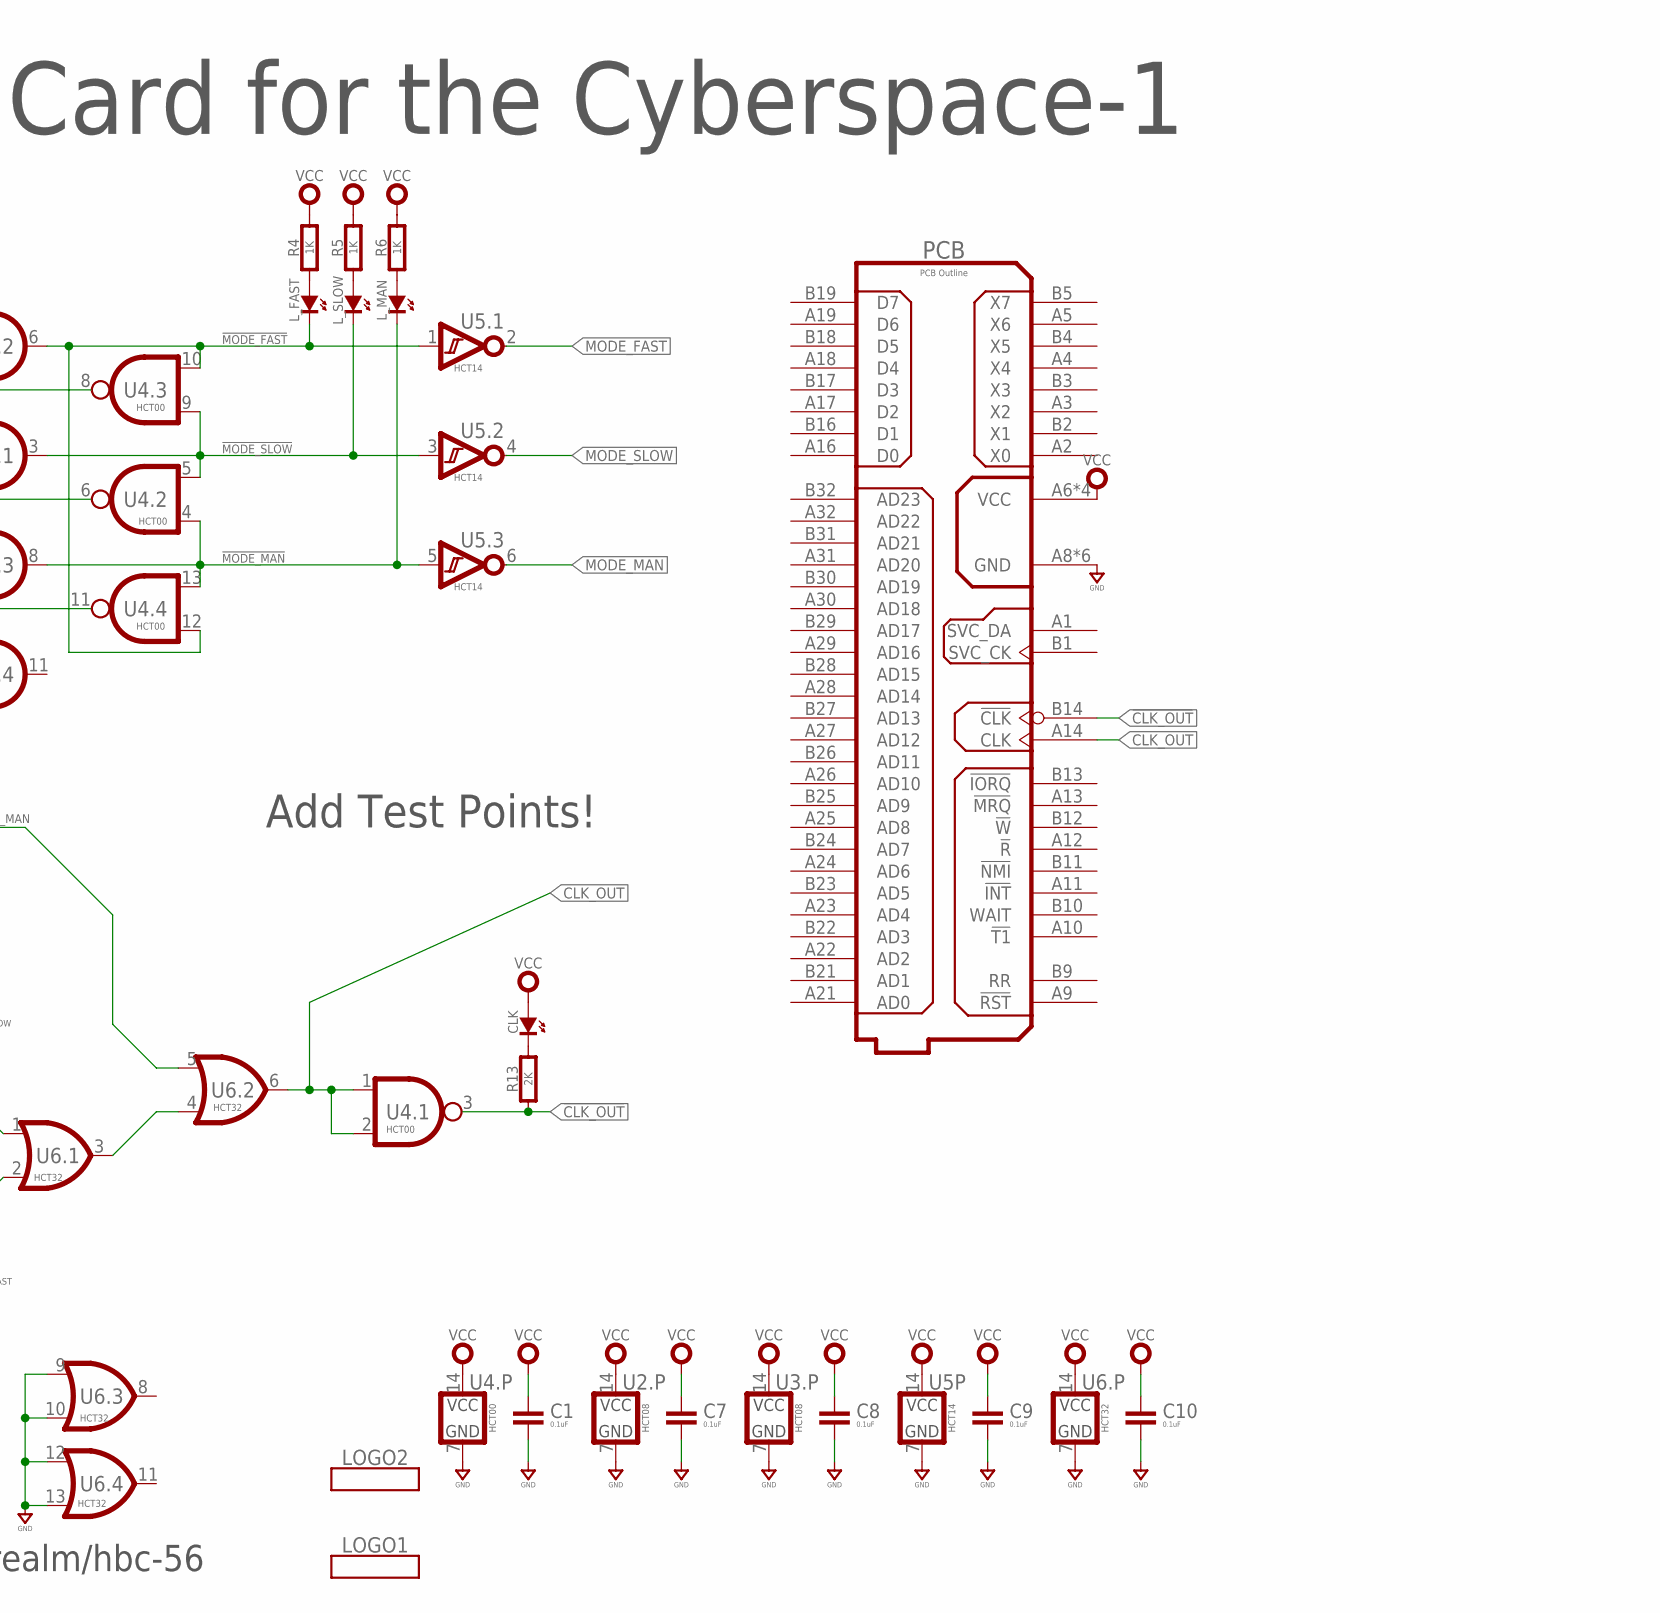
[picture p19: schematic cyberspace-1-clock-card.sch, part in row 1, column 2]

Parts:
C1, C3, C4, C7, C8, C9, C10, C11: 0.1uF; 0603-CAP
C2: 1uF; 0603-CAP
C5, C6: 22pF; 0603-CAP
CLK: SMT0603; SMD_0603
FAST: TACTILESPST-RA-6X6; TC-0202
LOGO1: SOZU-BRAND-LOGO-20MM; SOZU-20MM
LOGO2: CHRONOS-LOGO-20MM; CHRONOS2-20MM
L_FAST: SMT0603; SMD_0603
L_MAN: SMT0603; SMD_0603
L_SLOW: SMT0603; SMD_0603
MAN: TACTILESPST-RA-6X6; TC-0202
PCB: PCB Outline; CYBERSPACE-CARD-TYPE-1A
R1, R2, R3: 4.7K; 0603-RES
R4, R5, R6, R7, R8, R9, R10, R11: 1K; 0603-RES
R12: 1M; 0603-RES
R13: 2K; 0603-RES
SLOW: TACTILESPST-RA-6X6; TC-0202
SLOW_ADJ: 1M; CERMET_MULTI_3006P_THD
STEP: TACTILESPST-RA-6X6; TC-0202
U1: 555; SOP08
U2, U3: HCT08; SOP14
U4: HCT00; SOP14
U5: HCT14; SOP14
U6: HCT32; SOP14
U7: 74HCT1G-TSOP504; TSOP-5
X1: 1-14MHz; ATSXXXX

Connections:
!BTN_FAST: FAST.1, R1.1, U2.4 (A)
!BTN_MAN: MAN.1, R3.1, U2.9 (A)
!BTN_SLOW: R2.1, SLOW.1, U2.1 (A)
!CLK_OUT: PCB.B14 (!CLK), R13.1, U4.3 (Y)
!MODE_FAST: L_FAST.K (C), U2.6 (Y), U4.10 (A), U4.12 (B), U5.1 (A)
!MODE_MAN: L_MAN.K (C), U2.8 (Y), U4.4 (A), U4.13 (A), U5.5 (A)
!MODE_SLOW: L_SLOW.K (C), U2.3 (Y), U4.5 (B), U4.9 (B), U5.3 (A)
CLK_IN_FAST: U3.2 (B), U5.8 (Y)
CLK_IN_MAN: U3.9 (A), U5.12 (Y)
CLK_IN_SLOW: SLOW_ADJ.2CT (2), U1.3 (OUTPUT), U3.4 (A)
CLK_MAN_PRE_SCHMIDT: C2.1, R8.2, U5.13 (A)
CLK_OUT: PCB.A14 (CLK), U4.1 (A), U4.2 (B), U6.6 (Y)
CLK_OUT_FAST: U3.3 (Y), U6.2 (B)
CLK_OUT_MAN: U3.8 (Y), U6.5 (B)
CLK_OUT_SLOW: U3.6 (Y), U6.1 (A)
GND: C1.2, C2.2, C3.2, C5.2, C6.2, C7.2, C8.2, C9.2, C10.2, C11.2, FAST.2, MAN.2, PCB.A8 (GND), PCB.A15 (GND), PCB.A20 (GND), PCB.B8 (GND), PCB.B15 (GND), PCB.B20 (GND), SLOW.2, STEP.2, U1.1 (GND), U2.7 (GND), U2.12 (A), U2.13 (B), U3.7 (GND), U3.12 (A), U3.13 (B), U4.7 (GND), U5.7 (GND), U6.7 (GND), U6.9 (A), U6.10 (B), U6.12 (A), U6.13 (B), U7.3 (GND)
MODE_FAST: U3.1 (A), U5.2 (Y)
MODE_MAN: U3.10 (B), U5.6 (Y)
MODE_SLOW: U3.5 (B), U5.4 (Y)
unnamed: C3.1, R10.1, U1.2 (TRIGGER#), U1.6 (THRESHOLD)
unnamed: R9.1, U1.7 (DISCHARGE)
unnamed: C4.2, U1.5 (CONTROL)
unnamed: C6.1, R11.1, X1.2, X1.2SMD
unnamed: R10.2, SLOW_ADJ.3
unnamed: U6.3 (Y), U6.4 (A)
unnamed: L_FAST.A, R4.1
unnamed: R7.1, R8.1, STEP.1
unnamed: L_SLOW.A, R5.1
unnamed: L_MAN.A, R6.1
unnamed: CLK.K (C), R13.2
NOT_MODE_FAST: U2.5 (B), U4.6 (Y)
NOT_MODE_MAN: U2.10 (B), U4.8 (Y)
NOT_MODE_SLOW: U2.2 (B), U4.11 (Y)
VCC: C1.1, C4.1, C7.1, C8.1, C9.1, C10.1, C11.1, CLK.A, PCB.A6 (VCC), PCB.A7 (VCC), PCB.B6 (VCC), PCB.B7 (VCC), R1.2, R2.2, R3.2, R4.2, R5.2, R6.2, R7.2, R9.2, U1.4 (RESET#), U1.8 (VDD), U2.14 (VCC), U3.14 (VCC), U4.14 (VCC), U5.14 (VCC), U6.14 (VCC), U7.5 (VCC)
XTAL_IN: C5.1, R12.1, U5.11 (A), U7.2 (A), X1.1, X1.1SMD
XTAL_OUT: R11.2, R12.2, U5.9 (A), U5.10 (Y), U7.4 (Y)

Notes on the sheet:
Inspired by and based upon the HBC-56: https://github.com/visrealm/hbc-56
ONO-SENDAI -::- Clock Card for the Cyberspace-1
FAST CLOCK
SLOW CLOCK
STEP CLOCK
CLOCK MODE SELECT
Add Test Points!
Don't use Schmidt trigger for first buffer!
Clock Rework: - Lift U5 pins 10 and 11. - Connect U5 Pin 11 to GND. - Add U7 near X1. - Connect U7.3 to GND - COnnect U7.5 to Vcc - Connect U7.2 to R12/X1 junction. - Connect U7.4 to R12/R11 junction.

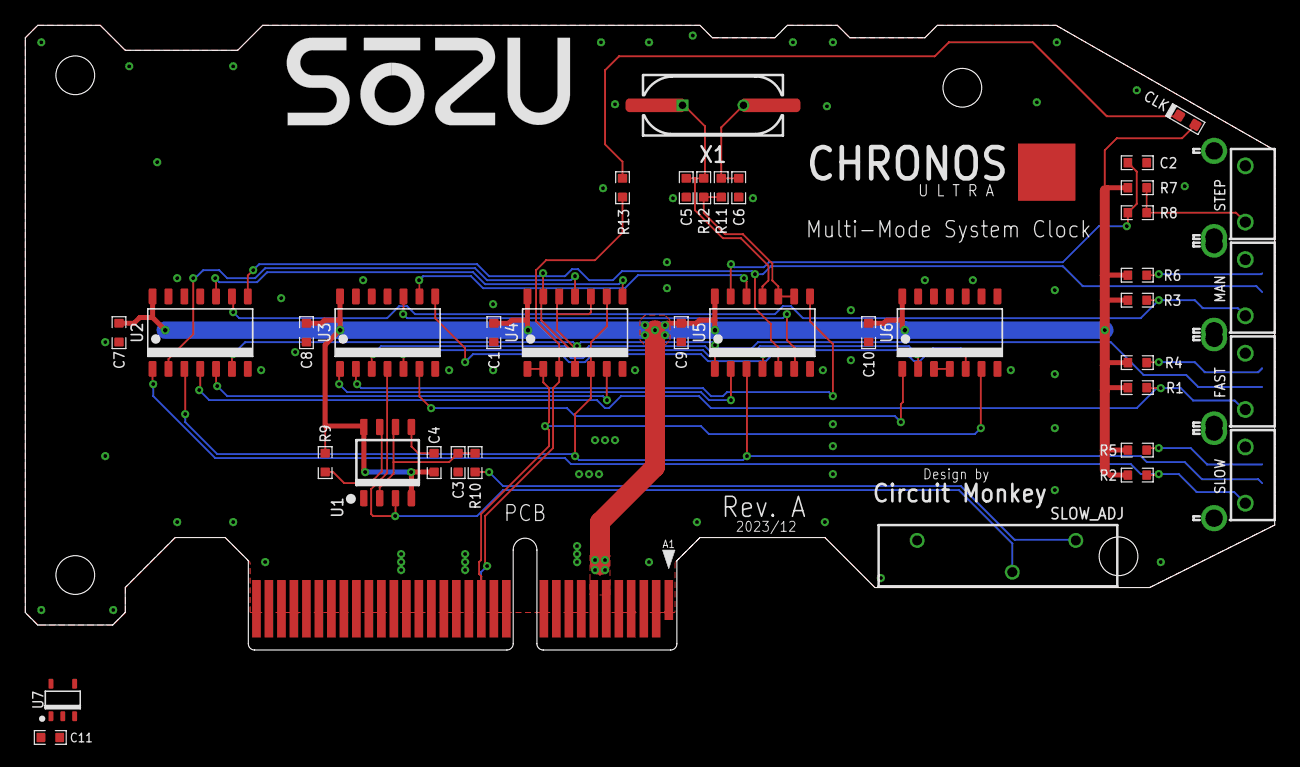
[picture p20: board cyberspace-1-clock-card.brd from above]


Board: 2 copper layers, 100.0 x 50.0 mm, 44 parts (3 on the bottom side), 36 nets.

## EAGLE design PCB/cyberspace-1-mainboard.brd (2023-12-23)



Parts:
!INT: BLU; SMD_0603
!IORQ: BLU; SMD_0603
!MRQ: BLU; SMD_0603
!NMI: BLU; SMD_0603
!R: BLU; SMD_0603
!T1: BLU; SMD_0603
!W: BLU; SMD_0603
AD0, AD1, AD2, AD3, AD4, AD5, AD6, AD7, AD8, AD9, AD10, AD11, AD12, AD13, AD14, AD15, AD16, AD17, AD18, AD19, AD20, AD21, AD22, AD23: BLU; SMD_0603
AUX0, AUX1, AUX2, AUX3, AUX4, AUX5, AUX6, AUX7: BLU; SMD_0603
C1, C2, C3, C4, C5, C6, C7: 1uF; 0603-CAP
C8, C9, C10, C11, C12, C13, C14, C20: 0.1uF; 0603-CAP
DAT0, DAT1, DAT2, DAT3, DAT4, DAT5, DAT6, DAT7: VIO; SMD_0603
ICSP: Connector, 6P, SM, VT; BM06B-SRSS-TB
J9, J10, J11, J12, J13, J14, J15: Header, 8-pin; MA08X1-VT-THD
J16: USB-C, Power; GCT-USB4125
M1: ATmega328P Module; 0119A
P_SW: 2-pin, VT, SMT; B2B-PH-SM4
QR00: QR_CODE-00-7MM; QR-7MM-00
QR01: QR_CODE-01-7MM; QR-7MM-01
QR02: QR_CODE-02-7MM; QR-7MM-02
QR03: QR_CODE-03-7MM; QR-7MM-03
QR04: QR_CODE-04-7MM; QR-7MM-04
QR05: QR_CODE-05-7MM; QR-7MM-05
QR06: QR_CODE-06-7MM; QR-7MM-06
QR07: QR_CODE-07-7MM; QR-7MM-07
R1, R2, R3, R4, R5, R6, R7, R8: 1K; 0603-RES
R9, R10, R11, R12, R13, R14, R15, R16, R17, R18, R19, R20, R21, R22, R23, R24, R25, R26, R27, R28, R29, R30, R31, R32, R33, R34, R35, R36, R37, R38, R39, R40, R41, R42, R43, R44, R45, R46, R47, R48, R49, R50, R51, R52, R53, R54, R55, R56: 2K; 0603-RES
R57, R58: 5.1K; 0603-RES
R59, R60, R61: 10K; 0603-RES
R62: 300; 0603-RES
RESET: Tact. Sw.; B3FS
RGB0, RGB1, RGB2, RGB3, RGB4, RGB5, RGB6, RGB7, RGB8, RGB9, RGB10, RGB11, RGB12, RGB13: SMART_LED4020-SIDE; SMD_4020
RST_EXT: JST, SH, 2P; BM02B-SRSS-TB
SERIAL: JST SM 3P; BM03B-SRSS-TB
SLOT0, SLOT1, SLOT2, SLOT3, SLOT4, SLOT5, SLOT6, SLOT7: Card Edge Socket, 64P; PCIE-64P-SOCKET
U1: RESET CKT; SOT-23
WAIT: BLU; SMD_0603

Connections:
!CLK: SLOT0.B14, SLOT1.B14, SLOT2.B14, SLOT3.B14, SLOT4.B14, SLOT5.B14, SLOT6.B14, SLOT7.B14
!INT: J13.4, R44.1, SLOT0.A11, SLOT1.A11, SLOT2.A11, SLOT3.A11, SLOT4.A11, SLOT5.A11, SLOT6.A11, SLOT7.A11
!IORQ: J13.7, R47.1, SLOT0.B13, SLOT1.B13, SLOT2.B13, SLOT3.B13, SLOT4.B13, SLOT5.B13, SLOT6.B13, SLOT7.B13
!MRQ: J13.8, R48.1, SLOT0.A13, SLOT1.A13, SLOT2.A13, SLOT3.A13, SLOT4.A13, SLOT5.A13, SLOT6.A13, SLOT7.A13
!NMI: J13.3, R43.1, SLOT0.B11, SLOT1.B11, SLOT2.B11, SLOT3.B11, SLOT4.B11, SLOT5.B11, SLOT6.B11, SLOT7.B11
!R: J13.6, R46.1, SLOT0.A12, SLOT1.A12, SLOT2.A12, SLOT3.A12, SLOT4.A12, SLOT5.A12, SLOT6.A12, SLOT7.A12
!RST: C20.1, ICSP.5, J15.3, M1.!RESET, R59.1, RESET.1, RESET.2 (1), RST_EXT.1, SLOT0.A9, SLOT1.A9, SLOT2.A9, SLOT3.A9, SLOT4.A9, SLOT5.A9, SLOT6.A9, SLOT7.A9, U1.2 (!RST)
!T1: J13.2, R42.1, SLOT0.A10, SLOT1.A10, SLOT2.A10, SLOT3.A10, SLOT4.A10, SLOT5.A10, SLOT6.A10, SLOT7.A10
!W: J13.5, R45.1, SLOT0.B12, SLOT1.B12, SLOT2.B12, SLOT3.B12, SLOT4.B12, SLOT5.B12, SLOT6.B12, SLOT7.B12
A0: J10.1, R17.1, SLOT0.A21, SLOT1.A21, SLOT2.A21, SLOT3.A21, SLOT4.A21, SLOT5.A21, SLOT6.A21, SLOT7.A21
A1: J10.2, R18.1, SLOT0.B21, SLOT1.B21, SLOT2.B21, SLOT3.B21, SLOT4.B21, SLOT5.B21, SLOT6.B21, SLOT7.B21
A2: J10.3, R19.1, SLOT0.A22, SLOT1.A22, SLOT2.A22, SLOT3.A22, SLOT4.A22, SLOT5.A22, SLOT6.A22, SLOT7.A22
A3: J10.4, R20.1, SLOT0.B22, SLOT1.B22, SLOT2.B22, SLOT3.B22, SLOT4.B22, SLOT5.B22, SLOT6.B22, SLOT7.B22
A4: J10.5, R21.1, SLOT0.A23, SLOT1.A23, SLOT2.A23, SLOT3.A23, SLOT4.A23, SLOT5.A23, SLOT6.A23, SLOT7.A23
A5: J10.6, R22.1, SLOT0.B23, SLOT1.B23, SLOT2.B23, SLOT3.B23, SLOT4.B23, SLOT5.B23, SLOT6.B23, SLOT7.B23
A6: J10.7, R23.1, SLOT0.A24, SLOT1.A24, SLOT2.A24, SLOT3.A24, SLOT4.A24, SLOT5.A24, SLOT6.A24, SLOT7.A24
A7: J10.8, R24.1, SLOT0.B24, SLOT1.B24, SLOT2.B24, SLOT3.B24, SLOT4.B24, SLOT5.B24, SLOT6.B24, SLOT7.B24
A8: J11.1, R25.1, SLOT0.A25, SLOT1.A25, SLOT2.A25, SLOT3.A25, SLOT4.A25, SLOT5.A25, SLOT6.A25, SLOT7.A25
A9: J11.2, R26.1, SLOT0.B25, SLOT1.B25, SLOT2.B25, SLOT3.B25, SLOT4.B25, SLOT5.B25, SLOT6.B25, SLOT7.B25
A10: J11.3, R27.1, SLOT0.A26, SLOT1.A26, SLOT2.A26, SLOT3.A26, SLOT4.A26, SLOT5.A26, SLOT6.A26, SLOT7.A26
A11: J11.4, R28.1, SLOT0.B26, SLOT1.B26, SLOT2.B26, SLOT3.B26, SLOT4.B26, SLOT5.B26, SLOT6.B26, SLOT7.B26
A12: J11.5, R29.1, SLOT0.A27, SLOT1.A27, SLOT2.A27, SLOT3.A27, SLOT4.A27, SLOT5.A27, SLOT6.A27, SLOT7.A27
A13: J11.6, R30.1, SLOT0.B27, SLOT1.B27, SLOT2.B27, SLOT3.B27, SLOT4.B27, SLOT5.B27, SLOT6.B27, SLOT7.B27
A14: J11.7, R31.1, SLOT0.A28, SLOT1.A28, SLOT2.A28, SLOT3.A28, SLOT4.A28, SLOT5.A28, SLOT6.A28, SLOT7.A28
A15: J11.8, R32.1, SLOT0.B28, SLOT1.B28, SLOT2.B28, SLOT3.B28, SLOT4.B28, SLOT5.B28, SLOT6.B28, SLOT7.B28
A16: J12.1, R33.1, SLOT0.A29, SLOT1.A29, SLOT2.A29, SLOT3.A29, SLOT4.A29, SLOT5.A29, SLOT6.A29, SLOT7.A29
A17: J12.2, R34.1, SLOT0.B29, SLOT1.B29, SLOT2.B29, SLOT3.B29, SLOT4.B29, SLOT5.B29, SLOT6.B29, SLOT7.B29
A18: J12.3, R35.1, SLOT0.A30, SLOT1.A30, SLOT2.A30, SLOT3.A30, SLOT4.A30, SLOT5.A30, SLOT6.A30, SLOT7.A30
A19: J12.4, R36.1, SLOT0.B30, SLOT1.B30, SLOT2.B30, SLOT3.B30, SLOT4.B30, SLOT5.B30, SLOT6.B30, SLOT7.B30
A20: J12.5, R37.1, SLOT0.A31, SLOT1.A31, SLOT2.A31, SLOT3.A31, SLOT4.A31, SLOT5.A31, SLOT6.A31, SLOT7.A31
A21: J12.6, R38.1, SLOT0.B31, SLOT1.B31, SLOT2.B31, SLOT3.B31, SLOT4.B31, SLOT5.B31, SLOT6.B31, SLOT7.B31
A22: J12.7, R39.1, SLOT0.A32, SLOT1.A32, SLOT2.A32, SLOT3.A32, SLOT4.A32, SLOT5.A32, SLOT6.A32, SLOT7.A32
A23: J12.8, R40.1, SLOT0.B32, SLOT1.B32, SLOT2.B32, SLOT3.B32, SLOT4.B32, SLOT5.B32, SLOT6.B32, SLOT7.B32
AUX0: J14.1, R49.1, SLOT0.A2, SLOT1.A2, SLOT2.A2, SLOT3.A2, SLOT4.A2, SLOT5.A2, SLOT6.A2, SLOT7.A2
AUX1: J14.2, R50.1, SLOT0.B2, SLOT1.B2, SLOT2.B2, SLOT3.B2, SLOT4.B2, SLOT5.B2, SLOT6.B2, SLOT7.B2
AUX2: J14.3, R51.1, SLOT0.A3, SLOT1.A3, SLOT2.A3, SLOT3.A3, SLOT4.A3, SLOT5.A3, SLOT6.A3, SLOT7.A3
AUX3: J14.4, R52.1, SLOT0.B3, SLOT1.B3, SLOT2.B3, SLOT3.B3, SLOT4.B3, SLOT5.B3, SLOT6.B3, SLOT7.B3
AUX4: J14.5, R53.1, SLOT0.A4, SLOT1.A4, SLOT2.A4, SLOT3.A4, SLOT4.A4, SLOT5.A4, SLOT6.A4, SLOT7.A4
AUX5: J14.6, R54.1, SLOT0.B4, SLOT1.B4, SLOT2.B4, SLOT3.B4, SLOT4.B4, SLOT5.B4, SLOT6.B4, SLOT7.B4
AUX6: J14.7, R55.1, SLOT0.A5, SLOT1.A5, SLOT2.A5, SLOT3.A5, SLOT4.A5, SLOT5.A5, SLOT6.A5, SLOT7.A5
AUX7: J14.8, R56.1, SLOT0.B5, SLOT1.B5, SLOT2.B5, SLOT3.B5, SLOT4.B5, SLOT5.B5, SLOT6.B5, SLOT7.B5
CC1: J16.A5 (CC1), R57.2
CC2: J16.B5 (CC2), R58.2
CLK: SLOT0.A14, SLOT1.A14, SLOT2.A14, SLOT3.A14, SLOT4.A14, SLOT5.A14, SLOT6.A14, SLOT7.A14
D0: J9.1, R9.1, SLOT0.A16, SLOT1.A16, SLOT2.A16, SLOT3.A16, SLOT4.A16, SLOT5.A16, SLOT6.A16, SLOT7.A16
D1: J9.2, R10.1, SLOT0.B16, SLOT1.B16, SLOT2.B16, SLOT3.B16, SLOT4.B16, SLOT5.B16, SLOT6.B16, SLOT7.B16
D2: J9.3, R11.1, SLOT0.A17, SLOT1.A17, SLOT2.A17, SLOT3.A17, SLOT4.A17, SLOT5.A17, SLOT6.A17, SLOT7.A17
D3: J9.4, R12.1, SLOT0.B17, SLOT1.B17, SLOT2.B17, SLOT3.B17, SLOT4.B17, SLOT5.B17, SLOT6.B17, SLOT7.B17
D4: J9.5, R13.1, SLOT0.A18, SLOT1.A18, SLOT2.A18, SLOT3.A18, SLOT4.A18, SLOT5.A18, SLOT6.A18, SLOT7.A18
D5: J9.6, R14.1, SLOT0.B18, SLOT1.B18, SLOT2.B18, SLOT3.B18, SLOT4.B18, SLOT5.B18, SLOT6.B18, SLOT7.B18
D6: J9.7, R15.1, SLOT0.A19, SLOT1.A19, SLOT2.A19, SLOT3.A19, SLOT4.A19, SLOT5.A19, SLOT6.A19, SLOT7.A19
D7: J9.8, R16.1, SLOT0.B19, SLOT1.B19, SLOT2.B19, SLOT3.B19, SLOT4.B19, SLOT5.B19, SLOT6.B19, SLOT7.B19
FX: M1.D7, R62.1
GND: !INT.K (C), !IORQ.K (C), !MRQ.K (C), !NMI.K (C), !R.K (C), !T1.K (C), !W.K (C), AD0.K (C), AD1.K (C), AD2.K (C), AD3.K (C), AD4.K (C), AD5.K (C), AD6.K (C), AD7.K (C), AD8.K (C), AD9.K (C), AD10.K (C), AD11.K (C), AD12.K (C), AD13.K (C), AD14.K (C), AD15.K (C), AD16.K (C), AD17.K (C), AD18.K (C), AD19.K (C), AD20.K (C), AD21.K (C), AD22.K (C), AD23.K (C), AUX0.K (C), AUX1.K (C), AUX2.K (C), AUX3.K (C), AUX4.K (C), AUX5.K (C), AUX6.K (C), AUX7.K (C), C1.2, C2.2, C3.2, C4.2, C5.2, C6.2, C7.2, C8.2, C9.2, C10.2, C11.2, C12.2, C13.2, C14.2, C20.2, DAT0.K (C), DAT1.K (C), DAT2.K (C), DAT3.K (C), DAT4.K (C), DAT5.K (C), DAT6.K (C), DAT7.K (C), ICSP.6, J15.5, J15.6, J15.7, J15.8, J16.A12 (GND), J16.B12 (GND), M1.GND, R1.2, R2.2, R3.2, R4.2, R5.2, R6.2, R7.2, R8.2, R57.1, R58.1, RESET.3 (2), RESET.4 (2), RGB0.4 (GND), RGB1.4 (GND), RGB2.4 (GND), RGB3.4 (GND), RGB4.4 (GND), RGB5.4 (GND), RGB6.4 (GND), RGB7.4 (GND), RGB8.4 (GND), RGB9.4 (GND), RGB10.4 (GND), RGB11.4 (GND), RGB12.4 (GND), RGB13.4 (GND), RST_EXT.2, SERIAL.3, SLOT0.A8, SLOT0.A15, SLOT0.A20, SLOT0.B8, SLOT0.B15, SLOT0.B20, SLOT1.A8, SLOT1.A15, SLOT1.A20, SLOT1.B8, SLOT1.B15, SLOT1.B20, SLOT2.A8, SLOT2.A15, SLOT2.A20, SLOT2.B8, SLOT2.B15, SLOT2.B20, SLOT3.A8, SLOT3.A15, SLOT3.A20, SLOT3.B8, SLOT3.B15, SLOT3.B20, SLOT4.A8, SLOT4.A15, SLOT4.A20, SLOT4.B8, SLOT4.B15, SLOT4.B20, SLOT5.A8, SLOT5.A15, SLOT5.A20, SLOT5.B8, SLOT5.B15, SLOT5.B20, SLOT6.A8, SLOT6.A15, SLOT6.A20, SLOT6.B8, SLOT6.B15, SLOT6.B20, SLOT7.A8, SLOT7.A15, SLOT7.A20, SLOT7.B8, SLOT7.B15, SLOT7.B20, U1.1 (GND), WAIT.K (C)
MISO: ICSP.1, M1.D12
MOSI: ICSP.4, M1.D11
unnamed: R1.1, SLOT7.B9
unnamed: DAT0.A, R9.2
unnamed: DAT1.A, R10.2
unnamed: DAT2.A, R11.2
unnamed: DAT3.A, R12.2
unnamed: DAT4.A, R13.2
unnamed: DAT5.A, R14.2
unnamed: DAT6.A, R15.2
unnamed: R2.1, SLOT6.B9
unnamed: DAT7.A, R16.2
unnamed: R3.1, SLOT5.B9
unnamed: AD0.A, R17.2
unnamed: R4.1, SLOT4.B9
unnamed: AD1.A, R18.2
unnamed: R5.1, SLOT3.B9
unnamed: AD2.A, R19.2
unnamed: R6.1, SLOT2.B9
unnamed: AD3.A, R20.2
unnamed: R7.1, SLOT1.B9
unnamed: AD4.A, R21.2
unnamed: R8.1, SLOT0.B9
unnamed: AD5.A, R22.2
unnamed: AD6.A, R23.2
unnamed: AD7.A, R24.2
unnamed: AD8.A, R25.2
unnamed: AD9.A, R26.2
unnamed: AD10.A, R27.2
unnamed: AD11.A, R28.2
unnamed: AD12.A, R29.2
unnamed: AD13.A, R30.2
unnamed: AD14.A, R31.2
unnamed: AD15.A, R32.2
unnamed: AD16.A, R33.2
unnamed: AD17.A, R34.2
unnamed: AD18.A, R35.2
unnamed: AD19.A, R36.2
unnamed: AD20.A, R37.2
unnamed: AD21.A, R38.2
unnamed: AD22.A, R39.2
unnamed: AD23.A, R40.2
unnamed: R41.2, WAIT.A
unnamed: !T1.A, R42.2
unnamed: !NMI.A, R43.2
unnamed: !INT.A, R44.2
unnamed: !W.A, R45.2
unnamed: !R.A, R46.2
unnamed: !IORQ.A, R47.2
unnamed: !MRQ.A, R48.2
unnamed: AUX0.A, R49.2
unnamed: AUX1.A, R50.2
unnamed: AUX2.A, R51.2
unnamed: AUX3.A, R52.2
unnamed: AUX4.A, R53.2
unnamed: AUX5.A, R54.2
unnamed: AUX6.A, R55.2
unnamed: AUX7.A, R56.2
unnamed: RGB0.3 (OUT), RGB1.1 (IN)
unnamed: RGB1.3 (OUT), RGB2.1 (IN)
unnamed: RGB2.3 (OUT), RGB3.1 (IN)
unnamed: RGB3.3 (OUT), RGB4.1 (IN)
unnamed: RGB4.3 (OUT), RGB5.1 (IN)
unnamed: RGB5.3 (OUT), RGB6.1 (IN)
unnamed: RGB6.3 (OUT), RGB7.1 (IN)
unnamed: RGB7.3 (OUT), RGB8.1 (IN)
unnamed: RGB8.3 (OUT), RGB9.1 (IN)
unnamed: RGB9.3 (OUT), RGB10.1 (IN)
unnamed: RGB10.3 (OUT), RGB11.1 (IN)
unnamed: RGB11.3 (OUT), RGB12.1 (IN)
unnamed: RGB12.3 (OUT), RGB13.1 (IN)
unnamed: R62.2, RGB0.1 (IN)
RX: M1.D0, SERIAL.2
SCK: ICSP.3, M1.D13
SVC_CK: J15.2, M1.A5, R60.1, SLOT0.B1, SLOT1.B1, SLOT2.B1, SLOT3.B1, SLOT4.B1, SLOT5.B1, SLOT6.B1, SLOT7.B1
SVC_DA: J15.1, M1.A4, R61.1, SLOT0.A1, SLOT1.A1, SLOT2.A1, SLOT3.A1, SLOT4.A1, SLOT5.A1, SLOT6.A1, SLOT7.A1
TX: M1.D1, SERIAL.1
VBUS: J16.A9 (VBUS), J16.B9 (VBUS), P_SW.2
VCC: C1.1, C2.1, C3.1, C4.1, C5.1, C6.1, C7.1, C8.1, C9.1, C10.1, C11.1, C12.1, C13.1, C14.1, ICSP.2, J15.4, M1.VCC, P_SW.1, R59.2, R60.2, R61.2, RGB0.2 (VDD), RGB1.2 (VDD), RGB2.2 (VDD), RGB3.2 (VDD), RGB4.2 (VDD), RGB5.2 (VDD), RGB6.2 (VDD), RGB7.2 (VDD), RGB8.2 (VDD), RGB9.2 (VDD), RGB10.2 (VDD), RGB11.2 (VDD), RGB12.2 (VDD), RGB13.2 (VDD), SLOT0.A6, SLOT0.A7, SLOT0.B6, SLOT0.B7, SLOT1.A6, SLOT1.A7, SLOT1.B6, SLOT1.B7, SLOT2.A6, SLOT2.A7, SLOT2.B6, SLOT2.B7, SLOT3.A6, SLOT3.A7, SLOT3.B6, SLOT3.B7, SLOT4.A6, SLOT4.A7, SLOT4.B6, SLOT4.B7, SLOT5.A6, SLOT5.A7, SLOT5.B6, SLOT5.B7, SLOT6.A6, SLOT6.A7, SLOT6.B6, SLOT6.B7, SLOT7.A6, SLOT7.A7, SLOT7.B6, SLOT7.B7, U1.3 (VCC)
WAIT: J13.1, R41.1, SLOT0.B10, SLOT1.B10, SLOT2.B10, SLOT3.B10, SLOT4.B10, SLOT5.B10, SLOT6.B10, SLOT7.B10



Board: 2 copper layers, 180.0 x 100.0 mm, 170 parts (62 on the bottom side), 134 nets.

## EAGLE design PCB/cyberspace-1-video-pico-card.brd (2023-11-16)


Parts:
A1H, A1L, A2H, A2L, A3H, A3L, A4H, A4L, A5H, A5L, A6H, A6L, A7H, A7L: SOLDER_JUMPER-80MIL-RND; SOLDER_JUMP_80MIL_RND
C1, C17: NP; 0603-CAP
C2: 10uF/16V; 0805-CAP
C3: 22uF/6.3V; 0805-CAP
C4, C5, C6, C7, C8, C8B, C9, C9B, C10, C11, C12, C16: 0.1uF; 0603-CAP
C13: 1uF; 0603-CAP
C14, C15: 27pF; 0603-CAP
J1: HDMI JACK; JAE-DC1-HDMI
J2: USB Micro-B; JAE-DX4R005
J3: Connector, 6P, SM, VT; BM06B-SRSS-TB
PCB: PCB Outline; CYBERSPACE-CARD-TYPE-1A
R1, R2: 27; 0603-RES
R3, R11, R13, R15, R18, R31, R32, R33: 2.2K; 0603-RES
R4, R5, R6, R7, R8, R9, R10: 4.7K; 0603-RES
R12, R14, R16, R17, R19: 3.3K; 0603-RES
R20, R21, R22, R23, R24, R25, R26, R27, R28, R29, R30: 270; 0603-RES
R34: 1K; 0603-RES
SW1: Tact. Sw.; B3FS
U1: RP2040-QFN; QFN56-7X7
U2: 74HCT688; TSSOP20
U3: TXB0108; TSSOP20
U4: FLASH, 128MBit; SOP08
VR1: 3.3V; SOT-223
X1: 12MHZ; 32X25

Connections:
1.1V: C8.1, C9.1, C13.1, U1.23 (DVDD), U1.45 (VREG_VOUT), U1.50 (DVDD)
!CE: R11.1, U2.19 (!P=Q)
!CLK: PCB.B14 (!CLK)
!INT: PCB.A11 (!INT)
!IORQ: PCB.B13 (!IORQ), U2.1 (!EN)
!MRQ: PCB.A13 (!MRQ)
!NMI: PCB.B11 (!NMI)
!R: PCB.A12 (!R), R18.1
!RST: PCB.A9 (!RST), R3.2
!T1: PCB.A10 (!T1)
!VID_CE: R11.2, R12.2, U1.32 (GP21), U3.10 (!OE)
!VID_R: R18.2, R19.2, U1.36 (GP24)
!VID_W: R15.2, R16.2, U1.35 (GP23)
!W: PCB.B12 (!W), R15.1
+3.3V: C3.1, C4.1, C5.1, C6.1, C7.1, C8B.1, C9B.1, C11.1, C16.1, R31.2, U1.1 (IOVDD), U1.10 (IOVDD), U1.22 (IOVDD), U1.33 (IOVDD), U1.42 (IOVDD), U1.43 (ADC_AVDD), U1.44 (VREG_VIN), U1.48 (USB_VDD), U1.49 (IOVDD), U3.2 (VCCA), U4.8 (VCC), VR1.2 (VOUT), VR1.TAB (VOUT)
A0: PCB.A21 (AD0), R13.1
A1: PCB.B21 (AD1), U2.2 (P0)
A2: PCB.A22 (AD2), U2.4 (P1)
A3: PCB.B22 (AD3), U2.6 (P2)
A4: PCB.A23 (AD4), U2.8 (P3)
A5: PCB.B23 (AD5), U2.11 (P4)
A6: PCB.A24 (AD6), U2.13 (P5)
A7: PCB.B24 (AD7), U2.15 (P6)
A8: PCB.A25 (AD8)
A9: PCB.B25 (AD9)
A10: PCB.A26 (AD10)
A11: PCB.B26 (AD11)
A12: PCB.A27 (AD12)
A13: PCB.B27 (AD13)
A14: PCB.A28 (AD14)
A15: PCB.B28 (AD15)
CARD_RR: PCB.B9 (RR)
CLK: PCB.A14 (CLK)
D0: PCB.A16 (D0), U3.20 (B1)
D1: PCB.B16 (D1), U3.18 (B2)
D2: PCB.A17 (D2), U3.17 (B3)
D3: PCB.B17 (D3), U3.16 (B4)
D4: PCB.A18 (D4), U3.15 (B5)
D5: PCB.B18 (D5), U3.14 (B6)
D6: PCB.A19 (D6), U3.13 (B7)
D7: PCB.B19 (D7), U3.12 (B8)
FLASH_!CS: U1.56 (QSPI_SS_N), U4.1 (!CS)
FLASH_SCK: U1.52 (QSPI_SCLK), U4.6 (CLK)
FLASH_SD0: U1.53 (QSPI_SD0), U4.5 (DI(IO0))
FLASH_SD1: U1.55 (QSPI_SD1), U4.2 (DO(IO1))
FLASH_SD2: U1.54 (QSPI_SD2), U4.3 (!WP!(IO2))
FLASH_SD3: U1.51 (QSPI_SD3), U4.7 (!RESET!(IO3))
GND: A1L.2, A2L.2, A3L.2, A4L.2, A5L.2, A6L.2, A7L.2, C1.2, C2.2, C3.2, C4.2, C5.2, C6.2, C7.2, C8.2, C8B.2, C9.2, C9B.2, C10.2, C11.2, C12.2, C13.2, C14.2, C15.2, C16.2, C17.2, J1.2 (GND), J1.5 (GND), J1.8 (GND), J1.11 (GND), J1.17 (GND), J2.5 (GND), J3.6, PCB.A8 (GND), PCB.A15 (GND), PCB.A20 (GND), PCB.B8 (GND), PCB.B15 (GND), PCB.B20 (GND), R12.1, R14.1, R16.1, R17.1, R19.1, SW1.1, SW1.2 (1), U1.19 (TESTEN), U1.PAD (GND), U2.10 (GND), U2.17 (P7), U3.11 (GND), U4.4 (GND), VR1.1 (GND)
unnamed: J1.13 (CEC), R20.2
unnamed: R1.2, U1.47 (USB_DP)
unnamed: R2.2, U1.46 (USB_DM)
unnamed: J1.12 (CK-), R21.2
unnamed: J1.10 (CK+), R22.2
unnamed: J1.9 (D0-), R23.2
unnamed: J1.7 (D0+), R24.2
unnamed: J1.6 (D1-), R25.2
unnamed: J1.4 (D1+), R26.2
unnamed: J1.3 (D2-), R27.2
unnamed: A1H.1, R4.2
unnamed: A1H.2, A1L.1, U2.3 (Q0)
unnamed: A2H.1, R5.2
unnamed: A2H.2, A2L.1, U2.5 (Q1)
unnamed: A3H.1, R6.2
unnamed: A3H.2, A3L.1, U2.7 (Q2)
unnamed: A4H.1, R7.2
unnamed: A4H.2, A4L.1, U2.9 (Q3)
unnamed: A5H.1, R8.2
unnamed: A5H.2, A5L.1, U2.12 (Q4)
unnamed: A6H.1, R9.2
unnamed: A6H.2, A6L.1, U2.14 (Q5)
unnamed: A7H.1, R10.2
unnamed: A7H.2, A7L.1, U2.16 (Q6)
unnamed: J1.1 (D2+), R28.2
unnamed: J1.15 (SCL), R29.2, R32.1
unnamed: J1.16 (SDA), R30.2, R33.1
unnamed: C1.1, J1.MTG1 (SHLD), J1.MTG2 (SHLD), J1.MTG3 (SHLD), J1.MTG4 (SHLD)
unnamed: R34.2, U1.21 (XOUT)
unnamed: C14.1, R34.1, X1.1
unnamed: C15.1, U1.20 (XIN), X1.3
unnamed: C17.1, J2.MTG1 (MNT), J2.MTG2 (MNT), J2.MTG3 (MNT), J2.MTG4 (MNT), J2.MTG5 (MNT), J2.MTG6 (MNT), J2.MTG7 (MNT), J2.MTG8 (MNT), J2.MTG9 (MNT), J2.MTG10 (MNT)
RUN/!RST: R3.1, R17.2, SW1.3 (2), SW1.4 (2), U1.26 (RUN)
SWCLK: J3.2, U1.24 (SWCLK)
SWDIO: J3.1, U1.25 (SWDIO)
UART_RX: J3.4, U1.28 (GP17)
UART_TX: J3.3, U1.27 (GP16)
UC_DVI_CEC: R20.1, R31.1, U1.31 (GP20)
UC_DVI_CK+: R22.1, U1.12 (GP09)
UC_DVI_CK-: R21.1, U1.11 (GP08)
UC_DVI_D0+: R24.1, U1.14 (GP11)
UC_DVI_D0-: R23.1, U1.13 (GP10)
UC_DVI_D1+: R26.1, U1.16 (GP13)
UC_DVI_D1-: R25.1, U1.15 (GP12)
UC_DVI_D2+: R28.1, U1.18 (GP15)
UC_DVI_D2-: R27.1, U1.17 (GP14)
UC_DVI_SCL: R29.1, U1.30 (GP19)
UC_DVI_SDA: R30.1, U1.29 (GP18)
USB_D+: J2.3 (D+), R1.1
USB_D-: J2.2 (D-), R2.1
USB_VBUS: J2.1 (VCC)
VCC: C2.1, C10.1, C12.1, PCB.A6 (VCC), PCB.A7 (VCC), PCB.B6 (VCC), PCB.B7 (VCC), R4.1, R5.1, R6.1, R7.1, R8.1, R9.1, R10.1, U2.20 (VCC), U3.19 (VCCB), VR1.3 (VIN)
VID_A0: R13.2, R14.2, U1.34 (GP22)
VID_D0: U1.2 (GP00), U3.1 (A1)
VID_D1: U1.3 (GP01), U3.3 (A2)
VID_D2: U1.4 (GP02), U3.4 (A3)
VID_D3: U1.5 (GP03), U3.5 (A4)
VID_D4: U1.6 (GP04), U3.6 (A5)
VID_D5: U1.7 (GP05), U3.7 (A6)
VID_D6: U1.8 (GP06), U3.8 (A7)
VID_D7: U1.9 (GP07), U3.9 (A8)
VID_VBUS: J1.18 (VBUS), R32.2, R33.2
WAIT: PCB.B10 (WAIT)

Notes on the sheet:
NOT USED

Board: 2 copper layers, 78 parts (0 on the bottom side), 94 nets, no tracks yet.

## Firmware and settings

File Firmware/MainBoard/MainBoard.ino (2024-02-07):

/**
 * CYBERspace1 - Mainboard Firmware
 *
 * Written by Mark Koch for https://github.com/CircuitMonkey/cyberspace-1
 */

#include <Adafruit_NeoPixel.h>
#ifdef __AVR__
 #include <avr/power.h>
#endif

#define M328_LED  SCK
#define M328_LED_COUNT 1
#define LED_PIN    7
#define LED_COUNT 14

Adafruit_NeoPixel strip(LED_COUNT, LED_PIN, NEO_GRB + NEO_KHZ800);
Adafruit_NeoPixel m328Led(M328_LED_COUNT, M328_LED, NEO_GRB + NEO_KHZ800);

void setup() {
  m328Led.begin();
  m328Led.setBrightness(30);
  m328Led.setPixelColor(0, strip.Color(100,   0,   100));
  m328Led.show();

  strip.begin();           // INITIALIZE NeoPixel strip object (REQUIRED)
  strip.show();            // Turn OFF all pixels ASAP
  strip.setBrightness(50); // Set BRIGHTNESS to about 1/5 (max = 255)
}

void loop() {
  // Fill along the length of the strip in various colors...
  colorWipe(strip.Color(255,   0,   0), 50); // Red
  colorWipe(strip.Color(  0, 255,   0), 50); // Green
  colorWipe(strip.Color(  0,   0, 255), 50); // Blue

  // Do a theater marquee effect in various colors...
  theaterChase(strip.Color(127, 127, 127), 50); // White, half brightness
  theaterChase(strip.Color(127,   0,   0), 50); // Red, half brightness
  theaterChase(strip.Color(  0,   0, 127), 50); // Blue, half brightness

  rainbow(10);             // Flowing rainbow cycle along the whole strip
  theaterChaseRainbow(50); // Rainbow-enhanced theaterChase variant
}

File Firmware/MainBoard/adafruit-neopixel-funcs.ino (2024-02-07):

/**
 * This file contents are Copyright by AdaFruit and used under license terms.
 *
 */

 
// Some functions of our own for creating animated effects -----------------

// Fill strip pixels one after another with a color. Strip is NOT cleared
// first; anything there will be covered pixel by pixel. Pass in color
// (as a single 'packed' 32-bit value, which you can get by calling
// strip.Color(red, green, blue) as shown in the loop() function above),
// and a delay time (in milliseconds) between pixels.
void colorWipe(uint32_t color, int wait) {
  for(int i=0; i<strip.numPixels(); i++) { // For each pixel in strip...
    strip.setPixelColor(i, color);         //  Set pixel's color (in RAM)
    strip.show();                          //  Update strip to match
    delay(wait);                           //  Pause for a moment
  }
}

// Theater-marquee-style chasing lights. Pass in a color (32-bit value,
// a la strip.Color(r,g,b) as mentioned above), and a delay time (in ms)
// between frames.
void theaterChase(uint32_t color, int wait) {
  for(int a=0; a<10; a++) {  // Repeat 10 times...
    for(int b=0; b<3; b++) { //  'b' counts from 0 to 2...
      strip.clear();         //   Set all pixels in RAM to 0 (off)
      // 'c' counts up from 'b' to end of strip in steps of 3...
      for(int c=b; c<strip.numPixels(); c += 3) {
        strip.setPixelColor(c, color); // Set pixel 'c' to value 'color'
      }
      strip.show(); // Update strip with new contents
      delay(wait);  // Pause for a moment
    }
  }
}

// Rainbow cycle along whole strip. Pass delay time (in ms) between frames.
void rainbow(int wait) {
  // Hue of first pixel runs 5 complete loops through the color wheel.
  // Color wheel has a range of 65536 but it's OK if we roll over, so
  // just count from 0 to 5*65536. Adding 256 to firstPixelHue each time
  // means we'll make 5*65536/256 = 1280 passes through this loop:
  for(long firstPixelHue = 0; firstPixelHue < 5*65536; firstPixelHue += 256) {
    // strip.rainbow() can take a single argument (first pixel hue) or
    // optionally a few extras: number of rainbow repetitions (default 1),
    // saturation and value (brightness) (both 0-255, similar to the
    // ColorHSV() function, default 255), and a true/false flag for whether
    // to apply gamma correction to provide 'truer' colors (default true).
    strip.rainbow(firstPixelHue);
    // Above line is equivalent to:
    // strip.rainbow(firstPixelHue, 1, 255, 255, true);
    strip.show(); // Update strip with new contents
    delay(wait);  // Pause for a moment
  }
}

// Rainbow-enhanced theater marquee. Pass delay time (in ms) between frames.
void theaterChaseRainbow(int wait) {
  int firstPixelHue = 0;     // First pixel starts at red (hue 0)
  for(int a=0; a<30; a++) {  // Repeat 30 times...
    for(int b=0; b<3; b++) { //  'b' counts from 0 to 2...
      strip.clear();         //   Set all pixels in RAM to 0 (off)
      // 'c' counts up from 'b' to end of strip in increments of 3...
      for(int c=b; c<strip.numPixels(); c += 3) {
        // hue of pixel 'c' is offset by an amount to make one full
        // revolution of the color wheel (range 65536) along the length
        // of the strip (strip.numPixels() steps):
        int      hue   = firstPixelHue + c * 65536L / strip.numPixels();
        uint32_t color = strip.gamma32(strip.ColorHSV(hue)); // hue -> RGB
        strip.setPixelColor(c, color); // Set pixel 'c' to value 'color'
      }
      strip.show();                // Update strip with new contents
      delay(wait);                 // Pause for a moment
      firstPixelHue += 65536 / 90; // One cycle of color wheel over 90 frames
    }
  }
}

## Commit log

2023-11-16 Mid-November work-in-process checkpoint.
    All schematics complete. All board placement finished. Needs routing.
    [cyberspace-1-clock-card.brd, cyberspace-1-clock-card.sch, cyberspace-1-cpu-card.brd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]
2023-11-22 Board routed. Needs tuning.
    [cyberspace-1-mainboard.brd]
2023-11-25 Mainboard DRC passed. New stand-in logo.
    [cyberspace-1-mainboard.brd, cyberspace-1-mainboard.sch]
2023-11-28 CPU PCB routed.
    [cyberspace-1-cpu-card.brd, cyberspace-1-cpu-card.sch]
2023-12-06 Clock Card final?
    [cyberspace-1-clock-card.brd, cyberspace-1-clock-card.sch]
2023-12-23 Tune mainboard routing.
    [cyberspace-1-mainboard.brd]
2023-12-23 PCBs as FABed 12-2023
2024-01-12 Resistor missing value.
    [cyberspace-1-clock-card.brd, cyberspace-1-clock-card.sch]
2024-01-12 BOM and some photos.
    [cyberspace-1-clock-card-bom.ods]
2024-01-21 Add clock card BOM.
    [cyberspace-1-clock-card-bom.ods]
2024-01-21 Update BOM
    [cyberspace-1-clock-card-bom.ods]
2024-01-22 WIP. Proposed clock fix in schematic.
    [cyberspace-1-clock-card.brd, cyberspace-1-clock-card.sch]
2024-02-02 Routed RAM-ROM card. Almost there.
    [cyberspace-1-ram-rom-card.brd, cyberspace-1-ram-rom-card.sch]
2024-02-04 New RamRom using flash chip.
    [cyberspace-1-ram-rom-card.brd, cyberspace-1-ram-rom-card.sch]
2024-02-06 Add notes on edge connector.
    [cyberspace-1-ram-rom-card.sch]
2024-02-06 GitHub did something weird. All new files and no idea why.
    [cyberspace-1-cpu-card.brd, cyberspace-1-cpu-card.sch, cyberspace-1-rom-programmer.brd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]
2024-02-07 Create initial light show for Main Board
